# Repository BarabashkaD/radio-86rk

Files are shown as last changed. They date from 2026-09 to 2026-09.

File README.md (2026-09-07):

# Radio 86RK
Re-make of the Soviet Ham Radio computer published in Radio Magazine in 1986

## Hardware Documentation

## Table of Content
* [Introduction](#introduction)
* [Specifications](#specifications)
* [Verification](#verification)
* [KiCad 10](#kicad-10)
  * [Prerequisites](#prerequisites)
  * [Mechanical export, for case design](#mechanical-export-for-case-design)
* [Project Notes](#project-notes)
* [Hardware Documentation](#hardware-documentation)
  * [Schematic and PCB Layout](#schematic-and-pcb-layout)
  * [Connectors](#connectors)
  * [Bill of Materials](#bill-of-materials)
  * [Memory Map](#memory-map)
* [Firmware Documentation](#firmware-documentation)
  * [Monitor](#monitor)
* [Release Notes](#release-notes)
  * [Changes](#changes)
  * [Known Issues](#known-issues)

## Introduction
This project is a remake of [Radio-86RK](https://en.wikipedia.org/wiki/Radio-86RK) - a soviet ham radio computer. The original design was published in Radio Magazine, an amateur radio and DIY electronics oriented publication, starting from [April 1986](Radio-86RK_Publications.md). Hence the "Radio" and "86" in the name ("RK" stands for ham radio computer).

The goal of the original design was to create a computer that can be built relatively easily and cheaply using commonly available components. Therefore it included several short-cuts. For example it didn't use 8228 bus controller. Instead, it uses */WR* and *DBIN* CPU signals instead to distinguish between write and read CPU cycles. Since the system doesn't decode I/O control signals, all the I/O devices are memory mapped. Another optimization is the use of DMA controller for both supplying the data to the CRT controller and for refreshing DRAMs. The system didn't support interrupts. The sound was implemented using *INTE* output of the CPU. The software would use **EI**/**DI** instructions to generate sound. There are no graphics capabilities. The font size was limited to 128 characters (8275 CRT controller limitation), and given that it had to support both Latin and Cyrillic ABCs, it only had capital letters for both ABCs. The CRT controller shares 16 MHz clock oscillator with the CPU (not uncommon in other home computers at that time period).

Despite the limitations, the design was fairly successful, many people have built this computer, and there are some that still building one, this project included. In addtion, several factories manufactured computers based on (but not always compatible with) this design - e.g. [Mikrosha](https://oldcomputer.info/8bit/mikrosha/index.htm), [Apogee BK-01](https://ru.wikipedia.org/wiki/%D0%90%D0%BF%D0%BE%D0%B3%D0%B5%D0%B9_%D0%91%D0%9A-01), and a few more.

### Specifications of the Original Design
  * KR580VM80A (Intel 8080) CPU @ 1.78 MHz (16 MHz divided by 9)
  * 16 KiB to 32 KiB DRAM, 2 KiB ROM (monitor software)
  * KR580VG75 (Intel 8275) CRT controller which works together with KR580VT57 (Intel 8257) DMA controller. 1 KiB ROM is used for font
  * Two KR580VV55A (Intel 8255A) PPIs. One is used for keyboard and cassette I/O, another one for the extension port
  * Normally the computer consisted of 2 or 3 PCBs - the mainboard, the keyboard, and the keypad.

### Modifications to the Original Design
 * 16 DRAM ICs replaced with a single 32 KiB SRAM IC
 * Font ROM size increased to 2 KiB, so that it fits an alternative font. CRT controller GPA0 attribute is used to switch between fonts.
 * Reverse video attribute implemented in CRT controller
 * Added 8251 USART and 8253 timer. The timer is used for dividing the clock for USART and for sound generation.
 * Single board design, including an integrated mechanical keyboard
 * The work is largely based on [Radio-86RК-SRAM](http://radio86rk.pbworks.com/w/page/58467718/Radio-86R%D0%9A-SRAM) project created by Alexey Khudyakov (alexcp).

Radio-86RK

## Specifications
* Processor: Intel 8080A / КР580ВМ80А CPU running at 1.78 MHz
* Memory:
  * RAM: 32 KiB SRAM
  * ROM: 2 KiB UV EPROM with system monitor software
* Video: Intel 8275 / КР580ВГ75 CRT Controller
  * Alphanumeric display
  * 2 KiB UV EPROM with font
  * Composite video output (50 Hz)
* Audio:
  * Intel 8253 / КР580ВИ53 (single channel)
  * CPU INTE output
* Parallel Interface:
  * Intel 8255А / КР580ВВ55А PPI
  * 26-pin expansion header
* Serial Interface:
  * Intel 8251А / КР580ВВ51А USART
  * DE-9 connector
* Built-in 67-keys keyboard
* Cassette recorder interface

## Verification

This repository includes a small, dependency-free harness that proves the
board's copper, connectivity and rule counts have not changed since the
committed baseline. Requires KiCad 10+ and Python 3.8+, no install step:

```
python3 tools/kicad-verify.py all
```

See [`tools/README.md`](tools/README.md) for the full command reference,
exit codes, and how to reuse it on another project.

## KiCad 10

This fork's KiCad files have been modernized to KiCad 10 format. **The board is
unchanged**: the gerber and drill output is identical to skiselev's v1.4, verified
automatically rather than asserted. All footprints and symbols are vendored into the
repository, so the project opens from a fresh clone with no external checkouts.

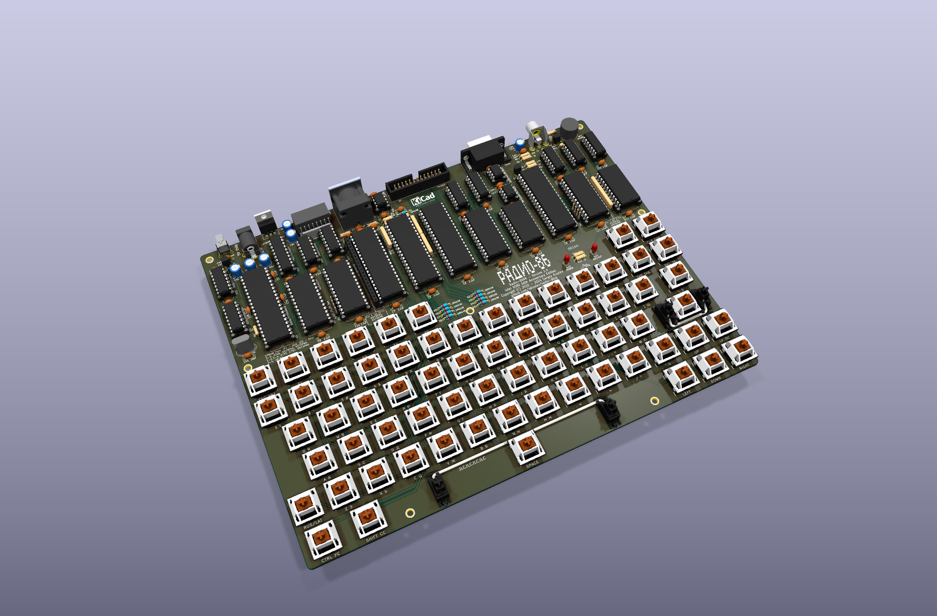
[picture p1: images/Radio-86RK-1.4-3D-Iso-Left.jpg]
Radio-86RK rendered from the KiCad 10 project


The rear panel, with every external connector in one row — composite video, serial,
parallel, cassette, sound and power:

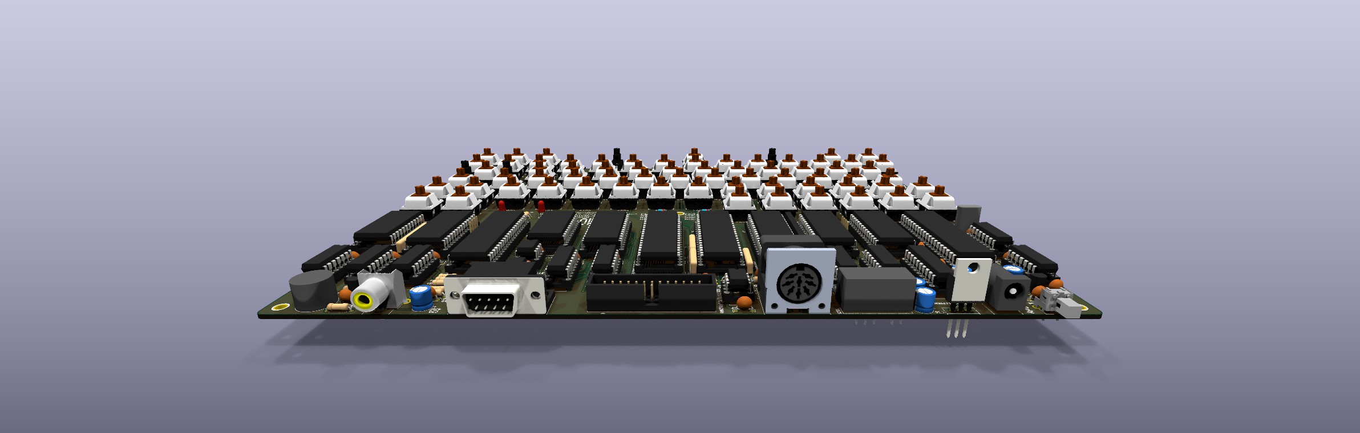
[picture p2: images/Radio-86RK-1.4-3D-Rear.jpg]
Rear connectors


Also rendered: [top](images/Radio-86RK-1.4-3D-Top.jpg) ·
[from the right](images/Radio-86RK-1.4-3D-Iso-Right.jpg) ·
[solder side](images/Radio-86RK-1.4-3D-Bottom.jpg), which carries the memory map, the
monitor command list and the subroutine table in silkscreen.

### Prerequisites

* **KiCad 10.0.4** or newer.
* The **Keyswitch Kicad Library**, v2.4, from KiCad's Plugin and Content Manager —
  package `com.github.perigoso.keyswitch-kicad-library`, upstream
  [github.com/kiswitch/keyswitch-kicad-library](https://github.com/kiswitch/keyswitch-kicad-library),
  CC-BY-SA-4.0. It supplies three model files that 69 of this board's 209 model
  references depend on: the Cherry MX switch body shared by all 67 keys, and two
  stabilizers. Without it the board still opens, routes and exports correctly — only the
  keyboard renders empty in the 3D view.

Check that everything resolves before trusting a render:

```
python3 tools/kicad-verify.py models
```

It reports 183 / 183 footprints covered when the library is installed, and names the
path variable responsible when it is not.

- [Modernization summary](docs/modernization-summary.md) — before/after, and how to re-verify
- [3D model sources](docs/3d-model-sources.md) — every model choice and substitution
- [Retained DRC violations](docs/drc-exclusions.md) — the 22 inherited from v1.4
- [Retained ERC violations](docs/erc-exclusions.md) — the 32 bus-label warnings
- [3D model follow-ups](docs/followup-3d-models.md) — the five approximations now resolved, and optional keycaps

### Mechanical export, for case design

```
python3 tools/export_mech.py            # STEP + placement CSV into .build/mech/
```

Writes four STEP files sharing one datum — the whole assembly, the parts needing panel
cutouts, the switches alone, and the bare board with its mounting holes — plus a CSV
giving every footprint's position, rotation, value and package.

Keycaps are deliberately absent. A cap is a case parameter rather than a board one: its
envelope drives the top-plate openings and the bezel height, and comparing profiles should
cost one filename, not a re-export. `placement.csv`'s `Package` column is the cap size, so
all 68 caps can be placed from the table.

## Project Notes

Check [Project Notes](Project_Notes.md) for the information about building this project

## Hardware Documentation

### Documentation for the Previous Versions

* [Version 1.3](https://github.com/skiselev/radio-86rk/tree/v1.3)
* [Version 1.2](https://github.com/skiselev/radio-86rk/tree/v1.2)
* [Version 1.1](https://github.com/skiselev/radio-86rk/tree/v1.1)

### Schematic and PCB Layout

* [Schematic - Version 1.4](KiCad/Radio-86RK-Schematic-1.4.pdf)
* [PCB Layout - Version 1.4](KiCad/Radio-86RK-Board-1.4.pdf)

### Connectors

#### J1 - Composite Video

Pin | Description     
--- | ---------------
Tip (the inner contact) | Output: Composite Video
Ring / Sleeve         |	Power: GND

#### J2 - Power (5V)
Connect regulated +5V power supply to this connector.

Note: The 8080A CPU, clock generator, and serial port transmitters and receivers use +12V/-5V/-12V voltages. An on-board DC-DC converter (U26) is used to obtain these voltages. Instead of using the DC-DC converter it is possible to provide these voltages directly to the system using J3 connector.

Pin | Description     
--- | ---------------
Tip (the inner contact) | Power: 5V (positive terminal)
Barrel / Sleeve         |	Power: GND (negative terminal)

#### J3 - Power (5V, 12V, -12V)
Connect regulated 5V/12V/-12V power supply to this connector.

Pin | Description     
--- | ---------------
1, 2, 3 | Power: GND
4, 5, 6 |	Power: 5V
7   |	Power: 12V
8   |	Power: -12V

#### J4 - Cassette Connector
Pin | Description     
--- | ---------------
1, 2, 3, 8   | Power: GND
4   |	Output: Sound output to cassette recorder (line level)
5   |	Input: Sound input from cassette recorder (line level)
6, 7 |	Not connected

#### J5 - Serial Port Connector
Pin | Description     
--- | ---------------
1   | Not connected: DCD
2   | Input: RX
3   | Output: TX
4   | Output: DTR
5   | Power: GND
6   | Input: DSR
7   | Output: RTS
8   | Input: CTS
9   | Not connected: RI

#### J6 - Parallel Port Connector
Pin | Description | Pin | Description
--- | ----------- | --- | ----------------
1   | Output: PC0 | 2   | Input: PA0
3   | Output: PC1 | 4   | Input: PA1
5   | Output: PC2 | 6   | Input: PA2
7   | Output: PC3 | 8   | Input: PA3
9   | Output: PC4 | 10  | Input: PA4
11  | Output: PC5 | 12  | Input: PA5
13  | Output: PC6 | 14  | Input: PA6
15  | Output: PC7 | 16  | Input: PA7
17  | Output: PB7 | 18  | Output: PB0
19  | Output: PB6 | 20  | Output: PB1
21  | Output: PB5 | 22  | Output: PB2
23  | Output: PB4 | 24  | Output: PB3
25  | Power: +5V  | 26  | Power: GND

### Bill of Materials

* [Radio-86RK project on Mouser.com](https://www.mouser.com/ProjectManager/ProjectDetail.aspx?AccessID=d3d8f92a02) - View and order all components except of the PCB, and most Intel 8xxx ICs.

* [Unicorn Electronics](https://www.unicornelectronics.com/prod.htm) is a good source for Intel 8xxx or compatible ICs, 7400-series TTL ICs, and 74LS00-series TTL-LS ICs

Component type     | Reference | Description                                 | Quantity | Possible sources and notes
------------------ | --------- | ------------------------------------------- | -------- | --------------------------
PCB                |           | Radio-86RK PCB                              | 1        | Buy from my Tindie store: [Radio-86RK - PCB](https://www.tindie.com/products/weird/radio-86rk-pcb/) or order from a PCB manufacturer of your choice using provided Gerber or KiCad files
Capacitor          | C1 - C32  | 0.1 uF, MLCC, 5 mm Pitch                    | 32       | Mouser [594-K104K15X7RF53H5](https://www.mouser.com/ProductDetail/594-K104K15X7RF53H5)
Capacitor          | C33 - C38 | 47 uF, 25V, Electrolytic or Organic Polymer | 6 	      | Mouser [80-A750EK476M1EAAE40](https://www.mouser.com/ProductDetail/80-A750EK476M1EAAE40)
Capacitor          | C39       | 0.22 uF, MLCC, 5 mm Pitch                   | 1        | Mouser [810-FG24X7R1H224KNT0](https://www.mouser.com/ProductDetail/810-FG24X7R1H224KNT0)
Capacitor          | C40       | 22 nF, MLCC, 5 mm Pitch                     | 1        | Mouser [810-FG28X7R1H223KNT0](https://www.mouser.com/ProductDetail/810-FG28X7R1H223KNT0)
Capacitor          | C41       | 10 nF, MLCC, 5 mm Pitch                     | 1        | Mouser [810-FG28X7R1H103KNT0](https://www.mouser.com/ProductDetail/810-FG28X7R1H103KNT0)
Capacitor          | C42       | 2.2 nF, MLCC, 5 mm Pitch                    | 1        | Mouser [810-FG28X7R1H222KNT0](https://www.mouser.com/ProductDetail/810-FG28X7R1H222KNT0)
Capacitor          | C43       | 1 nF, MLCC, 5 mm Pitch                      | 1        | Mouser [810-FG28C0G1H102JNT6](https://www.mouser.com/ProductDetail/810-FG28C0G1H102JNT6)
Capacitor          | C44       | 10 pF, MLCC, 5 mm Pitch                     | 1        | Mouser [810-FG28C0G1H100DNT00](https://www.mouser.com/ProductDetail/810-FG28C0G1H100DNT0)
Diode              | D1 - D9  | 1N4148                                       | 9        | Mouser [512-1N4148](https://www.mouser.com/ProductDetail/512-1N4148)
LED                | D10       | LED Indicator, 3 mm, Green                  | 1        | Mouser [630-HLMP-1503-C0002](https://www.mouser.com/ProductDetail/630-HLMP-1503-C0002)
LED                | D11       | LED Indicator, 3 mm, Yellow                 | 1        | Mouser [630-HLMP-1401](https://www.mouser.com/ProductDetail/630-HLMP-1401)
Polyfuse           | F1        | 1.1A, 5 mm Pitch                            | 1        | Mouser [576-16R110BU](https://www.mouser.com/ProductDetail/576-16R110BU)
Connector          | JP1, JP2  | 4 pin header, 2.54 mm Pitch                 | 2        | Mouser [649-68000-204HLF](https://www.mouser.com/ProductDetail/649-68000-204HLF)
Connector          | JP1, JP2  | Jumper, 2.54 mm Pitch                       | 4        | Mouser [806-SX1100-B)](https://www.mouser.com/ProductDetail/806-SX1100-B)
Connector          | J1        | RCA Phono connector, Yellow                 | 1        | Mouser [490-RCJ-014](https://www.mouser.com/ProductDetail/490-RCJ-014)
Connector          | J2        | DC Power Jack, 2mm                          | 1        | Mouser [806-KLDX-0202-A](https://www.mouser.com/ProductDetail/806-KLDX-0202-A)
Connector          | J3        | 8 pin friction lock connector               | 1        | Mouser [571-6404568](https://www.mouser.com/ProductDetail/571-6404568)
Connector          | J4        | DIN 8-pos, Right Angle, PCB mount           | 1        | Mouser [490-SDF-80J](https://www.mouser.com/ProductDetail/490-SDF-80J)
Connector          | J5        | Sub-D DE9M, Right Angle, PCB mount          | 1        | Mouser [523-L717SDE09P1ACH3R](https://www.mouser.com/ProductDetail/523-L717SDE09P1ACH3R)
Connector          | J6        | 13x2 pin header, shrouded                   | 1        | Mouser [517-30326-6002](https://www.mouser.com/ProductDetail/517-30326-6002)
Connector          | J7        | 20x1 pin socket                             | 1        | Mouser [517-929850-01-20-RB](https://www.mouser.com/ProductDetail/517-929850-01-20-RB). Note: Optional, for extension board connection
Transistor         | Q1, Q2    | 2N3904                                      | 2        | Mouser [512-2N3904TA](https://www.mouser.com/ProductDetail/512-2N3904TA)
Resistor           | R1        | 33 ohm                                      | 1        | Mouser [660-CF1/4CT52R330J](https://www.mouser.com/ProductDetail/660-CF1-4CT52R330J)
Resistor           | R2        | 75 ohm                                      | 1        | Mouser [660-CF1/4CT52R750J](https://www.mouser.com/ProductDetail/660-CF1-4CT52R750J)
Resistor           | R3        | 150 ohm                                     | 1        | Mouser [660-CF1/4CT52R151J](https://www.mouser.com/ProductDetail/660-CF1-4CT52R151J)
Resistor           | R4        | 330 ohm                                     | 1        | Mouser [660-CF1/4CT52R331J](https://www.mouser.com/ProductDetail/660-CF1-4CT52R331J)
Resistor           | R5        | 1.5 k                                       | 1        | Mouser [660-CF1/4CT52R152J](https://www.mouser.com/ProductDetail/660-CF1-4CT52R152J)
Resistor           | R6 - R13  | 1 k                                         | 8        | Mouser [660-CF1/4CT52R102J](https://www.mouser.com/ProductDetail/660-CF1-4CT52R102J)
Resistor           | R14       | 2.4 k                                       | 1        | Mouser [660-CF1/4CT52R242J](https://www.mouser.com/ProductDetail/660-CF1-4CT52R242J)
Resistor           | R15       | 12 k                                        | 1        | Mouser [660-CF1/4CT52R123J](https://www.mouser.com/ProductDetail/660-CF1-4CT52R123J)
Resistor Array     | RN1       | 10 k, SIP10                                 | 1        | Mouser [652-4610X-1LF-10K](https://www.mouser.com/ProductDetail/652-4610X-1LF-10K)
Resistor Array     | RN2 - RN4 | 4.7 k, SIP6                                 | 3        | Mouser [652-4606X-1LF-4.7K](https://www.mouser.com/ProductDetail/652-4606X-1LF-4.7K)
Speaker            | SP1       | 12 mm speaker                               | 1        | Mouser [665-AT-1224TWTR](https://www.mouser.com/ProductDetail/665-AT-1224TWTR)
Keyboard Switch    | SW1 - SW67 | Cherry MX Blue (Clicky)                    | 67       | Mouser [540-MX1A-E1NW](https://www.mouser.com/ProductDetail/540-MX1A-E1NW)
Switch Leveling Kit | SW11, SW64 | Leveling kit for MX 1x2, 1x2.25, 1x2.75   | 2        | Mouser [540-G99-0742](https://www.mouser.com/ProductDetail/540-G99-0742)
Switch Leveling Kit | SW64     | Leveling kit for MX 1x8                     | 1        | Mouser [540-G99-0226](https://www.mouser.com/ProductDetail/540-G99-0226) Note: Use the wire from this part and one of 540-G99-0742 to build a through hole leveling kit for the spacebar
Tactile Switch     | SW68      | 6 mm Tactile Switch Right Angle             | 1        | Mouser [653-B3F-3152](https://www.mouser.com/ProductDetail/653-B3F-3152)
Switch Keycap      | SW68      | 4 x 4 mmm Tactile Switch Key Cap, Orange    | 1        | Mouser [653-B32-1020](https://www.mouser.com/ProductDetail/653-B32-1020)
Integrated Circuit | U1        | Intel 8080A / КР580ВМ80А, CPU               | 1        | Unicorn Electronics [8080A](https://www.unicornelectronics.com/IC/8000.html), Jameco [52046](https://www.jameco.com/z/8080A-Major-Brands-IC-8080A-8-Bit-MOS-MPU_52046.html)
Integrated Circuit | U2        | Intel 8224 / КР580ГФ24, Clock Generator     | 1        | Unicorn Electronics [8224](https://www.unicornelectronics.com/IC/8000.html)
Integrated Circuit | U3        | Intel 8251А / КР580ВВ51А, USART             | 1        | Unicorn Electronics [8251A](https://www.unicornelectronics.com/IC/8000.html)
Integrated Circuit | U4        | Intel 8253 / КР580ВИ53, PIT                 | 1        | Unicorn Electronics [8253](https://www.unicornelectronics.com/IC/8000.html), Mouser [968-CP82C54Z](https://www.mouser.com/ProductDetail/968-CP82C54Z)
Integrated Circuit | U5, U6    | Intel 8255А / КР580ВВ55А, PPI               | 2        | Unicorn Electronics [8055A](https://www.unicornelectronics.com/IC/8000.html), Mouser [968-CP82C55A-5Z](https://www.mouser.com/ProductDetail/968-CP82C55A-5Z), Jameco [52732](https://www.jameco.com/z/8255A-5-Major-Brands-IC-8255A-5-Programmable-Peripheral-Interface-40-pin-DIP_52732.html)
Integrated Circuit | U7        | Intel 8257 / КР580ВТ57, DMA Controller      | 1        | Unicorn Electronics [8257](https://www.unicornelectronics.com/IC/8000.html)
Integrated Circuit | U8        | Intel 8275 / КР580ВГ75, CRT Controller      | 1        | Unicorn Electronics [8275](https://www.unicornelectronics.com/IC/8000.html), Jameco [52821](https://www.jameco.com/z/8275-Major-Brands-Programmable-CRT-Controller-DIP-40_52821.html)
Integrated Circuit | U9        | AS6C62256, SRAM 32Kx8                       | 1        | Mouser [913-AS6C62256-55PCN](https://www.mouser.com/ProductDetail/913-AS6C62256-55PCN), Unicorn Electronics [62256LP](https://www.unicornelectronics.com/IC/STATIC.html)
Integrated Circuit | U10, U11  | 2716 / КР573РФ5, 2Kx8 EPROM                 | 2        | Mouser [556-AT28C64B15PU](https://www.mouser.com/ProductDetail/556-AT28C64B15PU), Unicorn Electronics [2716](https://www.unicornelectronics.com/IC/EPROM.html). Note: 2716, 2732, 2764, 27C64 EPROMs, or 28C64 EEPROMs can be used
Integrated Circuit | U12       | 74LS373/К555ИР22, 8-bit Latch, 3-state outputs | 1     | Mouser [595-SN74LS373N](https://www.mouser.com/ProductDetail/595-SN74LS373N)
Integrated Circuit | U13       | 74198/К155ИР13, 8-bit Shift Register        | 1        | Unicorn Electronics [74198](https://www.unicornelectronics.com/IC/7400.html)
Integrated Circuit | U14       | 74LS138/К555ИД7, Decoder 3 to 8 active low outputs | 1 | Mouser [595-SN74LS138N](https://www.mouser.com/ProductDetail/595-SN74LS138N), Unicorn Electronics [74LS138](https://www.unicornelectronics.com/IC/74LS.html)
Integrated Circuit | U15       | 7492/К155ИЕ4, Divide by 12 counter          | 1        | Mouser [595-SN74LS92N](https://www.mouser.com/ProductDetail/595-SN74LS92N), Unicorn Electronics [74LS92](https://www.unicornelectronics.com/IC/74LS.html)
Integrated Circuit | U16       | 7486/К155ЛП5, Quad 2-input XOR              | 1        | Mouser [595-SN74LS86AN](https://www.mouser.com/ProductDetail/595-SN74LS86AN), Unicorn Electronics [74LS86](https://www.unicornelectronics.com/IC/74LS.html)
Integrated Circuit | U17       | 7474/К155ТМ2, Dual D Flip-flop, Set & Reset | 1        | Mouser [595-SN74LS74AN](https://www.mouser.com/ProductDetail/595-SN74LS74AN), Unicorn Electronics [74LS74](https://www.unicornelectronics.com/IC/74LS.html)
Integrated Circuit | U18       | 7408/К155ЛИ1, Quad 2-input AND              | 1        | Mouser [595-SN74LS08N](https://www.mouser.com/ProductDetail/595-SN74LS08N), Unicorn Electronics [74LS08](https://www.unicornelectronics.com/IC/74LS.html)
Integrated Circuit | U19       | 7404/К155ЛН1, Hex Inverter                  | 1        | Mouser [595-SN74LS04N](https://www.mouser.com/ProductDetail/595-SN74LS04N), Unicorn Electronics [74LS04](https://www.unicornelectronics.com/IC/74LS.html)
Integrated Circuit | U20       | 7400/К155ЛА3, Quad 2-input NAND             | 1        | Mouser [595-SN74LS00N](https://www.mouser.com/ProductDetail/595-SN74LS00N), Unicorn Electronics [74LS00](https://www.unicornelectronics.com/IC/74LS.html)
Integrated Circuit | U21       | TL071/К140УД6, Operational Amplifier        | 1        | Mouser [595-TL071IP](https://www.mouser.com/ProductDetail/595-TL071IP)
Integrated Circuit | U22       | SN75154N/К170УП2В, Quad RS-232 Receiver     | 1        | Mouser [595-SN75154N](https://www.mouser.com/ProductDetail/595-SN75154N), Unicorn Electronics [75154](https://www.unicornelectronics.com/IC/INTERFACE.html)
Integrated Circuit | U23, U24  | SN75150P/К170АП2, Dual RS-232 Driver        | 2        | Mouser [595-SN75150P](https://www.mouser.com/ProductDetail/595-SN75150P), Unicorn Electronics [75150](https://www.unicornelectronics.com/IC/INTERFACE.html)
Integrated Circuit | U25       | LM7905/КР1179ЕНВ, Negative 5V 1A Linear Regulator | 1  | Mouser [926-LM7905CT-NOPB](https://www.mouser.com/ProductDetail/926-LM7905CT-NOPB), Unicorn Electronics [7905T](https://www.unicornelectronics.com/IC/VOLT.html)
DC-DC Converter    | U26       | IZ0512, +/-12V +/-125mA, 4.5V-9V input      | 1        | Mouser [209-IZ0512S](https://www.mouser.com/ProductDetail/209-IZ0512S)
Integrated Circuit | U27       | DS1233-5, CPU Supervisory Circuit           | 1        | Mouser [700-DS1233-5T&R](https://www.mouser.com/ProductDetail/700-DS1233-5TR)
Crystal            | Y1        | 16 MHz, Series, HC-49U                      | 1        | Mouser [774-ATS160-E](https://www.mouser.com/ProductDetail/774-ATS160-E)
IC Socket          | U1, U5, U6, U7, U8 | 40 pin DIP                         | 5        | Mouser [649-DILB40P223TLF](https://www.mouser.com/ProductDetail/649-DILB40P223TLF), [517-4840-6000-CP](https://www.mouser.com/ProductDetail/517-4840-6000-CP)
IC Socket          | U3, U9, U10, U11    | 28 pin DIP                                  | 4        | Mouser [649-DILB28P223TLF](https://www.mouser.com/ProductDetail/649-DILB28P223TLF), [517-4828-6000-CP](https://www.mouser.com/ProductDetail/517-4828-6000-CP)
IC Socket          | U4, U13   | 24 pin DIP                          | 2        | Mouser [649-DILB24P-223TLF](https://www.mouser.com/ProductDetail/649-DILB24P-223TLF), [517-4824-6000-CP](https://www.mouser.com/ProductDetail/517-4824-6000-CP)
IC Socket          | U12       | 20 pin DIP                                  | 1        | Mouser [649-DILB20P-223TLF](https://www.mouser.com/ProductDetail/649-DILB20P-223TLF), [517-4820-3000-CP](https://www.mouser.com/ProductDetail/517-4820-3000-CP)
IC Socket          | U2, U14, U22 | 16 pin DIP                               | 3        | Mouser [649-DILB16P-223TLF](https://www.mouser.com/ProductDetail/649-DILB16P-223TLF), [517-4816-3000-CP](https://www.mouser.com/ProductDetail/517-4816-3000-CP)
IC Socket          | U15 - U20 | 14 pin DIP                                  | 6        | Mouser [649-DILB14P-223TLF](https://www.mouser.com/ProductDetail/649-DILB14P-223TLF), [517-4814-3000-CP](https://www.mouser.com/ProductDetail/517-4814-3000-CP)
IC Socket          | U21, U23, U24 | 8 pin DIP                               | 3        | Mouser [649-DILB8P223TLF](https://www.mouser.com/ProductDetail/649-DILB8P223TLF), [517-4808-3000-CP](https://www.mouser.com/ProductDetail/517-4808-3000-CP)

### Memory Map
* 0000h - 7FFFh - SRAM
  * 7600h - 7FFFh - Display buffer and monitor variables
* 8000h - 8FFFh - 8255A PPI (Keyboard, Cassette recorder, Sound control)
  * 8000h - Channel A data
  * 8001h - Channel B data
  * 8002h - Channel C data
  * 8003h - Control word
* 9000h - 9FFFh - 8253 Timer (USART Clock, Sound)
  * 9000h - Channel 0 count
  * 9001h - Channel 1 count
  * 9002h - Channel 2 count
  * 9003h - Control word
* 0A000h - 0AFFFh - 8255A PPI (Parallel Interface)
  * 0A000h - Channel A data
  * 0A001h - Channel B data
  * 0A002h - Channel C data
  * 0A003h - Control word
* 0B000h - 0BFFFh - 8251A USART
  * 0B000h - Data register
  * 0B001h - Command register
* 0C000h - 0CFFFh - 8275 CRT Controller
* 0D000h - 0DFFFh - Unused
* 0E000h - 0EFFFh - 8257 DMA Controller (write only)
* 0E000h - 0FFFFh - Monitor EPROM (read only)

## Firmware Documentation

### Monitor

#### Monitor Commands
* Memory Operations
  * **D\<Start_Address\>,\<End_Address\>** - Display memory content in hexadecimal
  * **L\<Start_Address\>,\<End_Address\>** - Display memory content in ASCII
  * **F\<Start_Address\>,\<End_Address\>,\<Value\>** - Fill memory with the specified value
  * **M\<Address\>** - Modify memory content
  * **T\<Start_Address\>,\<End_Address\>,\<Destination_Start_Address\>** - Copy memory block to destination
  * **C\<Start_Address\>,\<End_Address\>,\<Destination_Start_Address\>** - Compare memory block with destination
  * **S\<Start_Address\>,\<End_Address\>,\<Value\>** - Search memory for a value
  * **R\<ROM_Start_Address\>,\<ROM_End_Address\>,\<Destination_Start_Address\>** - Read from the ROM connected to the Parallel interface to memory
* Run Control
  * **G\<Start_Address\>\[,End_Address\]** - Run code, optionally stop at the specified address
  * **X** - Display and modify registers
* Cassette Input/Output
  * **O\<Start_Address\>,\<End_Address\>\[,Speed\]** - Write memory to cassette. Default speed is 1Dh / 1200 bps
  * **I\[Offset\]\[,Speed\]** - Read data from to cassette memory at specified offset

#### Monitor Subroutines:
* 0F803h - Keyboard input
  * Input: None
  * Output: A - character code read from keyboard
* 0F806h - Cassette input
  * Input: A=0FFh - with sync; A=08h - no sync
  * Output: A - data read from cassette
* 0F809h - Print character to screen
  * Input: C - character to print
* 0F80Ch - Cassette output
  * Input: C - data to write
* 0F812h - Query keyboard
  * Output: A=00h - key not pressed; A=0FFh - key pressed
* 0F815h - Print to screen in hex
  * Input: A - data to print
* 0F818h - Print string
  * Input: HL - string address
* 0F81Bh - Get key
  * Output: A=0FFh - key not pressed; A=0FEh - Rus/Lat; otherwise A - key code
* 0F81Eh - Get cursor position
  * Output: H - row, L - column
* 0F821h - Read character from screen at current cursor position
  * Output: A - char read from screen
* 0F824h - Read from cassette
  * Input: HL - offset of memory buffer to store data to
  * Output: HL - start; DE - end; BC - checksum

## Release Notes

### Changes
* Version 1.4
  * Change keyboard layout to QWERTY
  * Add the J7 extension connector
  * Add support for 2732, 2764 and 27C64 EPROMs and 28C64 EEPROM.

* Version 1.3
  * Fix issues from version 1.1 and version 1.2:
    * Use key labels "Ь X" and "СС SHIFT" on top silkscreen
    * Video signal generation circuit: use R2 = 75 Ohm and R5 = 1.5 kOhm
    
* Version 1.2
  * Add F5 key
  * Add copyright year on the top silkscreen

* Version 1.1
  * Fix all known issues of version 1.0
  * Use DS1233-5 mircoprocessor supervisor to generate reset signal
  * Implement reverse video attribute

* Version 1.0
  * Initial version

### Known Issues
* Version 1.3
  * No known issues

* Version 1.2
  * Top silkscreen: "Ь" and "X" key labels are swapped
  * Top silkscreen: More correct translation for "СС" is "SHIFT"
  * Video signal generation: Produced video Vpp and the backporch levels are a bit too high. Use R2 = 75 to 100 Ohm, and R5 = 1.5 kOhm for proper video signal levels (Reported by Martin Lukasek)
* Version 1.1
  * Top silkscreen: "Ь" and "X" key labels are swapped
  * Top silkscreen: More correct translation for "СС" is "SHIFT"
  * Top silkscreen: No copyright year
  * Video signal generation: Produced video Vpp and the backporch levels are a bit too high. Use R2 = 75 to 100 Ohm, and R5 = 1.5 kOhm for proper video signal levels (Reported by Martin Lukasek)

* Version 1.0
  * 8224 (U2) should use DIP-16 footprint
  * Down and Right buttons swapped
  * Reset RC does not provide enough time for the system to properly reset at power-on

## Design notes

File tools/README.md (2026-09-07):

# kicad-verify: a verification harness for KiCad projects

## What it does

This tool proves that a KiCad project's copper, connectivity and rule counts
have not changed since a known-good point. It compares the current board and
schematic against a captured baseline, and tells you exactly which of those
three things moved, if any.

It does not tell you whether your design is *good*. It tells you whether it
is *the same as before*, in the specific ways that are easy to break by
accident: a net silently reassigned, copper that shifted, a footprint that
lost a pad.

## How to run it

There is no install step. Clone the repository and run:

```
macOS / Linux:   python3 tools/kicad-verify.py all
Windows:         py tools\kicad-verify.py all
```

That runs every check (`gerber`, `netlist`, `rules`) and prints one verdict
line per gate, followed by a combined verdict for the run.

## Requirements

- KiCad 10 or newer (specifically `kicad-cli`, KiCad's command-line tool,
  which ships inside every KiCad 10 install).
- Any Python 3.8 or newer. The standard library only — nothing to `pip
  install`, no virtual environment, no configuration file.

The harness looks for `kicad-cli` in the usual per-OS install locations and
on `PATH`. If it cannot find one, or you want to point it at a specific
install, set the `KICAD_CLI` environment variable to the full path of the
`kicad-cli` executable:

```
export KICAD_CLI=/path/to/kicad-cli          # macOS / Linux
set KICAD_CLI=C:\path\to\kicad-cli.exe        # Windows
```

`KICAD_CLI` is authoritative once set: if it points at something that does
not run, the harness fails with an error naming that path rather than
silently falling back to some other `kicad-cli` it finds elsewhere on the
machine. That is deliberate — a tool that quietly ran a different KiCad than
the one you chose would be worse than one that stops and says so.

## The commands

Run as `python3 tools/kicad-verify.py <command>` (macOS / Linux) or
`py tools\kicad-verify.py <command>` (Windows).

| Command | What it does |
|---|---|
| `doctor` | Checks the environment: is `kicad-cli` found, is it new enough, is there a project, and is there a baseline the gates can actually use (`strict/` and `netlist.nets` present). Exits `0` if everything needed is present, `2` if not. Run this first when anything else fails unexpectedly. |
| `baseline` | Captures a new reference snapshot of the board's gerbers, drill files and netlist connectivity into `verify/baseline/`. Fails if a baseline already exists there; pass `--force` to overwrite it. Pass `--geometry` to instead capture (or refresh) the geometry-only baseline alongside it — see [Using `--geometry`](#using---geometry) below. |
| `gerber` | Exports gerbers and drill files from the current board, canonicalises them, and compares them against the committed baseline. Reports whether the copper is unchanged. |
| `netlist`  | Exports the netlist from the current schematic and compares its connectivity (which pin is on which net) against the baseline. Reports whether the wiring is unchanged. |
| `rules` | Runs ERC and DRC and reports the violation counts, by type. This is informational, not pass/fail — see [Why `rules` reports instead of judging](#why-rules-reports-instead-of-judging) below. |
| `models` | Reports which 3D model references resolve on this machine: how many footprints have a model KiCad can find, which do not, and which KiCad path variable is responsible when one cannot be resolved at all. Informational, like `rules`. Needs no `pcbnew` and no `kicad-cli` — it reads the board as text, so it still answers on a machine where KiCad is not set up, which is where the question usually arises. |
| `all` | Runs `gerber`, `netlist` and `rules` in order, and prints a combined verdict. This is the one command most people want. |
| `run` | `run <script> [args]` executes a script under the interpreter that can import `pcbnew` — the four model tools in `tools/` need it and no plain interpreter provides it. A passthrough: the script's stdout, stderr and exit code are its own, and no verdict line is written. Set `KICAD_PY` to override discovery. |
| `selftest` | Runs the harness's own internal checks (currently 24) against fixtures. Tests the tool itself, not your project — it needs no KiCad install and no board. |

Useful flags, valid on every command above: `--json` (emit one JSON document
instead of verdict lines), `--verbose` (show tool output that is normally
filtered as noise), `--project PCB` (point at a specific `.kicad_pcb` if more
than one exists), `--baseline-dir DIR` (use a baseline somewhere other than
`verify/baseline`). Two more flags apply to specific commands: `--force`
(`baseline`: overwrite an existing baseline of the same mode) and `--geometry`
(`baseline` and `gerber`: use the geometry-only baseline instead of the
committed strict one — see below).

## Verdict statuses

Each gate's line on stdout begins with one of three statuses, and `--json`
records the same value in that gate's `"status"` field. The one exception is
`run`, which writes no verdict line at all: it is a passthrough, so its stdout
belongs to the script it launched and its exit code is that script's.

| Status | Meaning |
|---|---|
| `PASS` | The gate ran and found no difference from the baseline. |
| `FAIL` | The gate ran and found a difference from the baseline. |
| `INFO` | The gate ran and is reporting a count, not a verdict. `rules` (see below) and `models`. An `INFO` gate never causes exit code `1`, and `all`'s combined "N of N gates passed" line does not count it either way. |

## Why `rules` reports instead of judging

`rules` runs ERC and DRC and prints the violation counts, by type. It always
returns `INFO`, never `PASS` or `FAIL`, and it never affects `all`'s exit
code.

There is no baseline for rule counts to compare against, on purpose: unlike
copper and connectivity, the number of ERC/DRC violations legitimately
changes as a project is worked on, and a change in that count is not
automatically a regression. It also means this repository's own current
counts can include violations that are already understood and accepted
rather than accidentally introduced: as of this writing, DRC reports 5
`starved_thermal` errors, a known property of this board's thermal relief
pattern, not something `rules` is equipped to distinguish from a genuine new
problem. Reading the counts and the by-type breakdown, and deciding whether a
change in them is expected, is on the person or agent running the tool.

## Using `--geometry`

`gerber`'s default ("strict") comparison includes the X2 net and component
name attributes KiCad embeds in each gerber, so a net rename shows up even
when no copper moved. `--geometry` drops those attributes and compares copper
shape only — for a change that legitimately renames nets without moving
anything.

The geometry baseline is deliberately not committed (only `strict/` and
`netlist.nets` are). To use it, capture it yourself into the same baseline
directory:

```
python3 tools/kicad-verify.py baseline --geometry
python3 tools/kicad-verify.py gerber --geometry
```

Capturing geometry never touches the committed `strict/` baseline, and
capturing strict never touches `geometry/` — each `--force` applies only to
the mode you are capturing. If you want to keep a geometry baseline out of
the repository entirely (recommended, since it is deliberately uncommitted),
point both commands at a directory outside the repo with `--baseline-dir`.

## The three exit codes, and why there are three and not two

| Exit code | Meaning |
|---|---|
| `0` | Every gate passed. Nothing changed. |
| `1` | A gate failed. The board genuinely changed. |
| `2` | A check could not run at all — no `kicad-cli` found, no baseline captured, no board in the repository, an unexpected error. |

This distinction is the single most important thing to understand about this
tool, and it is easy to get wrong if you only skim the output. `1` means
"the board changed." `2` means "I don't know, because the check never ran."
Those are different facts, and collapsing them is a real hazard: a script,
CI job, or agent that treats any non-zero exit as "a regression" will report
a copper change that never happened, just because `kicad-cli` was not on
`PATH` that day. Always branch on the exit code, not just on "zero or
non-zero."

## What the version warning means

If the harness runs under a different major version of KiCad than the one
that captured the current baseline, it prints a `VERSION-DRIFT` warning to
stderr and (in `--json` mode) sets `"version_drift": true` on the affected
gates.

This is **not** a failure, and it never changes the exit code by itself.
KiCad's own exporters occasionally change their output between major
versions in ways that are cosmetic — reordered attributes, a different
comment string — with no actual change to the board. The warning means: go
read the KiCad changelog for the version jump, and confirm that whatever
difference the gate reports (if any) is one of those emitter changes and not
a real one. It exists because those two situations look identical in a diff
but mean very different things.

## Using it on another project

This harness is not specific to this repository. To use it on a different
KiCad project, copy two things into it:

- `tools/kicad-verify.py`
- `tools/kicadverify/` (the whole directory)

Then, from inside that project's repository, run:

```
python3 tools/kicad-verify.py baseline
```

once, to capture the reference snapshot, and commit the resulting
`verify/baseline/` directory. After that, `python3 tools/kicad-verify.py all`
works the same way it does here. No project name, board name, or file path is
hard-coded anywhere in the tool — it discovers the `.kicad_pcb` in the
repository itself.

## What is deliberately not here

These were left out on purpose, not forgotten:

- **CI / GitHub Actions.** A workflow running `selftest` and `all` on every
  push would need a runner with KiCad 10 installed, which pins a specific
  KiCad version as its own piece of work. The harness's three exit codes,
  `--json` output, and lack of any interactive input are all there to make
  that straightforward to add later.
- **Packaging** the harness as a standalone, independently versioned
  component with its own repository.
- **A test framework** beyond `selftest`, should the harness ever grow past
  what its fixture-based checks can cover.

See also [`docs/harness-equivalence.md`](../docs/harness-equivalence.md) for
the evidence that this harness checks the same things the shell scripts it
replaced checked.

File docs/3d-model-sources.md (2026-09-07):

# 3D model sources and substitutions

Per the design spec's equivalence rubric, the 3D layer is appearance-only: it touches no
copper, so visually equivalent public models are preferred over exact ones. Every
substitution is recorded here.

Models attach to footprint *definitions*, not to references, which is why 76 components are
covered by 8 assignments. Paths use `${KICAD10_3DMODEL_DIR}`, `${KICAD10_3RD_PARTY}` or
`${KIPRJMOD}` so the project stays portable. KiCad 10 ships `.step` files, not `.wrl`.

Coverage is measured with `the `models` command`, which counts only models whose file
actually resolves — the board began with 109 footprints carrying KiCad-4-era references
(`dil/`, `discret/`, `pin_array/`) that pointed at nothing.

## Passives — 76 components, 8 footprints

| Footprint | Refs | Count | Model | Note |
|---|---|---:|---|---|
| `Res_762` | R1–R15 | 15 | `Resistor_THT/R_Axial_DIN0207_L6.3mm_D2.5mm_P7.62mm_Horizontal` | exact lead pitch |
| `Cap_Cer_508` | C1–C32, F1 | 39 | `Capacitor_THT/C_Disc_D5.0mm_W2.5mm_P5.00mm` | see F1 note |
| `Cap_Elec_Radial_6.3mm` | C33–C38 | 6 | `Capacitor_THT/CP_Radial_D6.3mm_P2.50mm` | exact |
| `Diode_762` | D1–D9 | 9 | `Diode_THT/D_DO-35_SOD27_P7.62mm_Horizontal` | exact |
| `LED_3mm` | D10, D11 | 2 | `LED_THT/LED_D3.0mm` | exact |
| `Crystal_HC-49U_Vert` | Y1 | 1 | `Crystal/Crystal_HC49-U_Vertical` | exact |
| `Transistor_TO92_EBC_254` | Q1, Q2, U27 | 3 | `Package_TO_SOT_THT/TO-92_Inline` | generic TO-92 for the Soviet KT-series |
| `IC_TO220-3_Vert` | U25 | 1 | `Package_TO_SOT_THT/TO-220-3_Vertical` | exact package |

**F1 renders as a disc capacitor.** F1 is a fuse but is placed on the `Cap_Cer_508`
footprint, and models attach to footprints rather than to references. Splitting the
footprint solely to change F1's appearance would mean a second library part with identical
copper — cost without benefit. Accepted under the tolerance policy.

**U27 is a TO-92 transistor, not a regulator.** The design spec's prose calls U25 and U27
regulators; the board says `Transistor_TO92_EBC_254`. The board is right.

## Socketed DIP ICs — 24 components, 7 footprints

Every DIP on this board sits in a socket, so each DIP footprint carries **two** models: the
socket at board level and the chip raised to the socket's seating height. U25 (TO-220),
U26 (SIP DC-DC) and U27 (TO-92) are not DIP parts and take a single model each.

| Footprint | Refs | Socket (z=0) | Chip (z=offset) | Offset |
|---|---|---|---|---:|
| `IC_DIP8_300` | U21, U23, U24 | `DIP-8_W7.62mm_Socket` | `DIP-8_W7.62mm` | 5.1 |
| `IC_DIP14_300` | U15–U20 | `DIP-14_W7.62mm_Socket` | `DIP-14_W7.62mm` | 5.48 |
| `IC_DIP16_300` | U2, U14, U22 | `DIP-16_W7.62mm_Socket` | `DIP-16_W7.62mm` | 5.48 |
| `IC_DIP20_300` | U12 | `DIP-20_W7.62mm_Socket` | `DIP-20_W7.62mm` | 5.48 |
| `IC_DIP24_600` | U4, U13 | `DIP-24_W15.24mm_Socket` | `DIP-24_W15.24mm` | 5.48 |
| `IC_DIP28_600` | U3, U9, U10, U11 | `DIP-28_W15.24mm_Socket` | `DIP-28_W15.24mm` | 5.48 |
| `IC_DIP40_600` | U1, U5–U8 | `DIP-40_W15.24mm_Socket` | `DIP-40_W15.24mm` | 5.48 |

Row spacing follows the board: `*_300` footprints are 300 mil (7.62 mm), `*_600` are
600 mil (15.24 mm).

**Where the heights come from.** The prototype uses Amphenol FCI DILB `-223TLF`
stamped-and-formed sockets. Amphenol's spec sheet publishes Dim A/B/C/D, pitch, row spacing
and tail length but no overall height. Distributor package data reports 5.48 mm for the 14,
16, 28 and 40 position parts and for the 0.3″ sibling `DILB24P-224TLF`, across both row
spacings and from 14 to 40 positions. Height is a property of the insulator's extruded
cross-section and does not vary with body length, so 5.48 mm is taken for the 20- and
24-pin as well. The 8-pin at 5.1 mm is the only outlier.

This is a 3D-appearance parameter, not a geometry one: a 0.38 mm error would be invisible
in the viewer and cannot reach the board.

**Western parts, not Soviet.** The prototype is populated with Intel `P8255A-5`, NEC
`8257C-5`, TI `SN74198N` and `74LS74` rather than the Soviet equivalents in the dual
silkscreen markings, so package choices follow the Western parts.

## Connectors, arrays and misc — 15 components, 12 footprints

| Footprint | Refs | Model | Fidelity |
|---|---|---|---|
| `Conn_SIL6` | RN2–RN4 | `Resistor_THT/R_Array_SIP6` | exact pin count and pitch |
| `Conn_SIL10` | RN1 | `Resistor_THT/R_Array_SIP10` | exact pin count and pitch |
| `Conn_Pin_Header_4x1_2.54mm` | JP1, JP2 | `PinHeader_1x04_P2.54mm_Vertical` | exact |
| `Conn_Pin_Header_20x1_2.54mm` | J7 | `PinSocket_1x20_P2.54mm_Vertical` | female — see below |
| `Conn_Pin_Header_13x2_2.54mm_Shrouded` | J6 | `IDC-Header_2x13_P2.54mm_Vertical` | exact |
| `Conn_Friction_Lock_8P_2.54mm` | J3 | `Radio86RK.3dshapes/640456-8` | **the real part** — see below |
| `Conn_Power_Jack_Circular_Pads` | J2 | `Radio86RK.3dshapes/KLDX-0202-A` | **the real part** |
| `Conn_Dsub_DE9M` | J5 | `DSUB-9_Pins_Horizontal_P2.77x2.84mm_EdgePinOffset7.70mm_Housed_MountingHolesOffset9.12mm` | housed, with mounting hardware |
| `Speaker_12mm` | SP1 | `Radio86RK.3dshapes/AT-1224-TWT-R` | **the real part** |
| `DC-DC_SIP8` | U26 | `Radio86RK.3dshapes/IZ0512S` | scaled sibling — see below |

`RN1`–`RN4` are SIP resistor networks, so `R_Array_SIP6`/`SIP10` are used rather than pin
headers — same pin count and pitch, correct body.

**J7 is a socket, not a header, despite its footprint name.** The name
`Conn_Pin_Header_20x1_2.54mm` is inherited from the board and cannot change without
changing a `lib_id`, but skiselev's BOM calls for a 3M **929850-01-20-RB** — a female
receptacle strip (Mouser 517-929850-01-20-RB) for the optional extension board. It rendered
as 20 male pins until this was caught in a render. KiCad's `PinSocket_1x20_P2.54mm_Vertical`
has pads identical to the header's, so only the model changed and the transform is
unaffected. J6 and JP1/JP2 were checked against the BOM at the same time and are genuinely
male headers.

### The seven KiCad does not ship

KiCad has no RCA, cinch or phono model, no 8-pin DIN, and nothing for the XP Power IZ
series — searched every installed `.3dshapes` directory including the PCM third-party
libraries. (The one "DIN" hit is `Jack_3.5mm_Ledino_KB3SPRS`, whose *part name* contains
the string.) Four more parts had a stock model that was the right *category* and the wrong
manufacturer.

All seven came from the abandoned `migrate2kicad10` branch, which attacked the same problem
from the opposite end: it replaced each footprint with a manufacturer-sourced one that
carried its own model. Those footprint swaps moved copper and are unusable here — but a
model does not care which footprint introduced it, and the STEP files are the real parts
from skiselev's BOM. They are vendored into `KiCad/Radio86RK.3dshapes/` and referenced via
`${KIPRJMOD}`, so a fresh clone renders them with nothing installed.

| Ref | Part | STEP origin |
|---|---|---|
| J1 | Same Sky / CUI **RCJ-014** RCA phono | SnapEDA (`CUI_DEVICES_RCJ-014.step`) |
| J2 | Kycon **KLDX-0202-A** 2 mm DC jack | SamacSys / Ultra Librarian (`KLDX-0202-A.STEP`) |
| J3 | TE / AMP **640456-8** MTA-100 header | Tyco Electronics (`C-640456-8`, 2013) |
| J4 | Same Sky / CUI **SDF-80J** DIN-8 | manufacturer (`same sky SDF-80J.STEP`) |
| SP1 | PUI **AT-1224-TWT-R** 12 mm transducer | SamacSys, via FreeCAD/OCC |
| SW68 | Omron **B3F-3152** tactile | manufacturer (`B3F_3152.step`) |
| U26 | XP Power **IZ0512S** DC-DC | sibling IA0512S, scaled — below |

**The models are checked against our pads before being reused.** Two libraries drawing the
same part is a premise, not a fact, so `tools/align_models_legacy.py` brute-forces the four
90° rotations, lands our pad 1 on theirs, and reports the worst distance from any of our
pads to the nearest same-named pad of theirs:

| Footprint | fit rotation | worst pad residual |
|---|---:|---:|
| `DC-DC_SIP8` | 0° | 0.0000 mm |
| `Conn_DIN_8pin` | 180° | 0.0000 mm |
| `Conn_Friction_Lock_8P_2.54mm` | 180° | 0.0000 mm |
| `Switch_Tactile_6mm_Right` | 180° | 0.0009 mm |
| `Speaker_12mm` | 90° | 0.0024 mm |
| `Conn_Power_Jack_Circular_Pads` | 0° | 0.1006 mm |
| `Conn_RCA_Right` | 0° | 0.5800 mm |

J1's 0.58 mm is a known error in the *board's* own hand-drawn footprint: measured against
the RCJ-01 datasheet, the manufacturer's signal-to-odd-ground spacing is right and the
board's is 0.58 mm out. It is copper, so it stays as it is; at the 3D layer it is invisible.

#### U26 is the one model that is not the real part

No STEP exists for the IZ0512S anywhere. The old branch substituted the manufacturer's
model for the sibling **IA0512S** — same potted-SIP construction — and scaled it to the IZ's
body. That is a sound approach, and its two ratios were right, but they were applied to the
wrong axes.

The branch's note orders both parts *L × H × W*: IA `19.3 × 10.1 × 6.0`, IZ
`21.85 × 11.10 × 9.20`. The IZ figures are correct — page 1 of
`Documentation/XP Power - DC-DC Converter - IZ Series.pdf` gives 0.86″ (21.85) long,
0.44″ (11.10) high and 0.36″ (9.20) wide on the bottom view. But the STEP itself is authored
Z-up, so *its* axes run L × W × H; measuring the file gives X 19.30, Y 6.09, Z −5.00…10.16.
Stored as `(1.1321, 1.0990, 1.5333)` the height ratio lands on width and the width ratio on
height, rendering U26 about **15.6 mm tall and 6.7 mm thick** instead of 11.10 × 9.20 — a
brick with the right footprint and visibly wrong proportions, filling only part of the v1.4
silkscreen outline.

Corrected to `(1.1321, 1.5107, 1.0925)` in `align_models_legacy.py`'s `SCALE_FIX`, so
re-running the tool reproduces the fix rather than the bug. The body now fills its silk
outline. The board is designed to accept alternatives anyway (README: Traco TMR 3E, Recom
RS3, Cincon EC3SA), so a correctly-proportioned SIP brick of the right family is a fair
representation even though the mould is a sibling's.

#### Licensing

All seven are vendor-published mechanical models, redistributed from the manufacturer or
from SnapEDA / Ultra Librarian exports of manufacturer data. They are geometry for
documentation and rendering, carry no copper, and are not part of the fabrication output —
the gerbers are byte-identical with or without them.

## Keyboard — 68 switches, 6 footprints

| Footprint | Refs | Model(s) | Note |
|---|---|---|---|
| `CHERRY_PCB_100H` | 62 keys | `SW_Cherry_MX_PCB` | perigoso, via PCM |
| `CHERRY_PCB_125H` | SW65, SW66 | `SW_Cherry_MX_PCB` | |
| `CHERRY_PCB_150H` | SW61 | `SW_Cherry_MX_PCB` | |
| `CHERRY_PCB_225H` | SW11 | `SW_Cherry_MX_PCB` + `Stabilizer_Cherry_MX_2.00u` | composite |
| `CHERRY_PCB_625H` | SW64 | `SW_Cherry_MX_PCB` + `Stabilizer_Cherry_MX_6.25u` @ 180° | composite, mirrored |
| `Switch_Tactile_6mm_Right` | SW68 | `Radio86RK.3dshapes/B3F-3152` | reset switch, the real Omron part |

**The footprints are the board's own, not perigoso's.** Only the models come from perigoso.
The design spec proposed adopting perigoso's footprints on the grounds that doing so
"brings a 3D model", but models attach to any footprint by name, and both libraries put the
switch's centre guide boss at (0, 0) — verified — so the model lands correctly on the
original geometry with no offset.

Keeping the board's footprints avoided a 2.286 → 2.5 mm pad growth on 67 switches, the
compensating schematic pin swap, two clearance violations at 0.150 mm needing prototype
measurement, and the loss of SW11/SW64's stabilizer holes. Cost: perigoso's tidier
silkscreen and a real `F.CrtYd` courtyard. Cherry specifies hole sizes (⌀1.5 mm terminals,
⌀4.0 mm boss, ⌀1.7 mm locating pins), not land diameter, so the board's 2.286 mm pads are
as legitimate as perigoso's 2.5 mm.

### Why SW64's stabilizer is rotated 180°

The board mounts the spacebar stabilizer opposite to the 2.25u one, in the footprint's own
frame:

| | ⌀3.9878 (housing) | ⌀3.048 (wire) |
|---|---|---|
| Board SW11 (2.25u) | y = +8.255 | y = −6.985 |
| perigoso `Stabilizer_2.00u` | y = +8.225 | y = −6.985 |
| Board SW64 (6.25u) | y = **−8.255** | y = **+6.985** |
| perigoso `Stabilizer_6.25u` | y = **+8.225** | y = **−6.985** |

A 180° rotation about Z maps (x, y) → (−x, −y). Both patterns are symmetric about x = 0, so
it acts as a pure front-to-back flip and aligns the model with the board's holes. Verified
in a close render of the spacebar row: the housings sit on the board with the wire
spanning between them. At 0° the whole assembly hangs off the board edge, 16.5 mm out.

Per skiselev's README BOM, SW11 and SW64 take Cherry **G99-0742** leveling kits
(Mouser `540-G99-0742`), and SW64 additionally uses the **wire from a G99-0226** (MX 1x8,
`540-G99-0226`) fitted into G99-0742 housings. That hybrid is why SW64's 100.076 mm spacing
matches no stock 6.25u part, and why perigoso's is 38 µm out and mirrored. The stabilizer
models sit 30 µm (SW11) and 38 µm (SW64) from the board's actual hole centres — invisible in
the viewer, and exactly what the 3D tolerance policy exists to permit.

## Coverage

**183 / 183.** The 7 mounting holes and the silkscreen logo are exempt. Nothing is missing:
J4, the last gap, was closed with the manufacturer's own SDF-80J model.

## Validating the render

Automated checks catch missing models; they cannot catch a model that is present but wrong.
Do both.

### Scripted

```bash
python3 tools/kicad-verify.py models                 # counts only resolving models
python3 tools/kicad-verify.py models  # names what has none
```

Coverage counts a footprint as covered only if the model file exists on disk. The board
began with 109 footprints carrying KiCad-4-era references that pointed at nothing, so
"has a model entry" would have scored those as covered.

### Visual, in KiCad

PCB Editor → **View → 3D Viewer** (`Alt+3`). Left-drag rotates, scroll zooms.
**Preferences → Display Options → Raytracing** for a realistic render.
Hiding the board itself makes floating or sunk parts obvious.

### Visual, scripted

Top-down views hide Z errors. A low camera angle is what exposes them:

```bash
# the shot that validates seating heights
kicad-cli pcb render --output check.png --width 1600 --height 700 --quality high \
  --rotate '-72,0,0' --zoom 2.2 --pivot '-2.0,3.0,0' --perspective board.kicad_pcb
```

Reproduce the views this was checked against — renders are build output and are not
committed:
`tools/render.py --view iso-left dip` for socket seating, and `--view back profile` for
switch heights, where the edge-on elevation shows them against each other.

### What to check, and why each could be wrong

| Check | Expected | Failure mode |
|---|---|---|
| DIP seating | chip sitting *in* a socket, socket rails visible beneath | wrong Z offset — 5.1 mm for 8-pin, 5.48 mm otherwise |
| SW64 spacebar | two stabilizer housings straddling the switch, wire between, all **on** the board | wrong rotation — at 0° the assembly hangs 16.5 mm off the edge |
| SW11 (2.25u) | same, no rotation | |
| Edge connectors J2, J5, J6 | bodies pointing **outward** past the board edge | model orientation |
| Y1 crystal | standing upright | vertical vs horizontal model |
| Switch row | uniform height, all flat on the board | |
| J1 | a yellow RCA phono jack, opening past the board edge | wrong rotation would face it inward |
| J4 | a round DIN socket overhanging the edge, body inside its silk outline | composed transform wrong |
| J5 | black housing filling the silk outline, bosses on the two plated mounting holes | wrong housed variant |
| U26 | a squat brick filling its silk outline, not a tall thin one | swapped scale axes |

All of these were checked on the current board and are correct.

## Model alignment — why offsets and rotations are needed

A 3D model is authored in the coordinate frame of the KiCad footprint it ships with. Our
footprints came from a 1986 board through a different library and use different
conventions, so a model dropped in at offset (0,0,0) lands wrong. Three distinct mismatches
were found, all of them by looking at the render:

| Mismatch | Effect | Example |
|---|---|---|
| KiCad puts **pad 1 at the origin**; ours are **centred** | model sits half a pitch off — one lead in a hole, one in mid-air | `Cap_Cer_508` pads at ±2.54; KiCad's at 0 and +5.0 |
| KiCad's DIPs run their long axis along **Y**; ours along **X** | every IC appears rotated 90° | `IC_DIP40_600` is 48.26 × 15.24; KiCad's is 15.24 × 48.26 |
| Some of ours number pads in the **opposite direction** | body reversed — a diode's cathode band at the wrong end | `Diode_762` pad 1 at +3.81; KiCad's at 0 |

None of this touches copper. It is purely how the model is placed for rendering, which is
why both gerber gates passed throughout while the render was visibly wrong.

**KiCad's 3D model offset has Y inverted relative to PCB coordinates** (the 3D view has Y
up, the board has Y down); the Z rotation is not inverted. That was determined empirically
with a calibration board rendering eight candidate conventions
side by side against KiCad's own DIP-40 as a known-good reference, and only one puts the
chip body between its pad rows. It is also why the passives looked right while every IC was
visibly wrong: the passives all have `off_y` = 0, so the inversion changes nothing for them.

`tools/align_models.py` derives the transform from geometry rather than guessing: it takes
the pad-1 → pad-N vector in each footprint, rotates by the angle between them, and
translates so the model's pad 1 lands on ours. The results are written into `models.tsv` as
explicit `off_x`, `off_y`, `off_z`, `rot_z` columns, so the data records what is applied and
the tool records why.

Of 27 footprints with stock KiCad models, **only the switches needed no correction** — and
those were verified separately, since both libraries put the switch's centre boss at (0,0).

### Manufacturer models need two more degrees of freedom

KiCad's own models are all authored Z-up in the footprint frame, so `off_x, off_y, off_z,
rot_z` is enough for them. Vendor models are not: they arrive in whatever frame the vendor's
CAD used — several of these are exported lying on their side and need `rot_x = -90` — and
the U26 substitution needs a scale. `models.tsv` therefore takes five optional trailing
columns, `rot_x rot_y sx sy sz`, defaulting to 0 and 1.

The transforms for those seven are *composed*, not measured: each model already had a
placement inside the old branch's own footprint, and our footprint differs from theirs by a
Z rotation θ and a translation. KiCad renders a model as

```
translate(offset) . Rz(-rot_z) . Ry(-rot_y) . Rx(-rot_x) . scale
```

so pre-multiplying Rz(θ) gives `translate(Rz(θ)·offset + δ) . Rz(-(rot_z + θ)) . Ry . Rx .
scale` — the stored Z rotations simply add, `rot_x`/`rot_y`/`scale` pass through, and the
old offset is rotated by θ before δ is added. `tools/align_models_legacy.py` does this and
prints the rows. J4 is the case that proves the algebra: θ = 180° over a non-zero offset and
an X rotation, and the model lands inside its silkscreen outline to the pixel.

**Automated coverage cannot catch this.** the `models` command proves a model file resolves;
it says nothing about whether the model is placed correctly. Only the render does. See the
validation section above.

### Connector alignment, verified

Checked numerically (does the transform map every pad?) and visually:

| Ref | Footprint | rot | worst pad error | Visual |
|---|---|---:|---:|---|
| J5 | `Conn_Dsub_DE9M` | 180° | 0.107 mm | housing fills the silk outline, shell past the board edge, bosses on the mounting holes |
| J6 | `Conn_Pin_Header_13x2_2.54mm_Shrouded` | 270° | 0.000 mm | shroud opening faces up |
| J7 | `Conn_Pin_Header_20x1_2.54mm` | 270° | 0.000 mm | a socket body with a row of receptacle holes, not pins |
| JP1, JP2 | `Conn_Pin_Header_4x1_2.54mm` | 270° | 0.000 mm | pins on pads, body within the silk outline |
| RN1 | `Conn_SIL10` | 0° | 0.000 mm | |
| RN2–RN4 | `Conn_SIL6` | 0° | 0.000 mm | |
| J3 | `Conn_Friction_Lock_8P_2.54mm` | 180° | 0.000 mm | posts on pads (rotation changed with the 640456-8 model) |

J5's 0.107 mm is KiCad's generic 2.77/2.84 mm DSUB pitch against the board's exact
2.7432/2.8448 (0.108"/0.112"). Neither matters at the 3D layer.

**J5 uses a housed variant, and our footprint does have somewhere to put the hardware.** Its
two 3.05 mm pads named `0` at ±12.494 are the connector's plated mounting holes, sitting on
the centreline between the pin rows — there are no *non-plated* holes, which is a different
thing. Of KiCad's five housed right-angle DE9 models, three put their mounting holes on that
centreline; the `EdgePinOffset4.94mm` and `EdgePinOffset14.56mm_...Offset8.20mm` variants
put them at row-2 height instead, a real mechanical mismatch rather than a naming one. The
three survivors differ only in how far the shell stands off the pins, and the board's near
pin row sits 8.178 mm from the edge, so `EdgePinOffset7.70mm` is the fit and the shell
overhangs by 0.478 mm.

Reference renders: `validate-ic-alignment.png`, `validate-connectors.png`,
`validate-jumpers.png`.

### Polarity, verified against the netlist

Placement being right does not mean *orientation* is right — a diode can sit perfectly on
its pads with the band at the wrong end. Checked through the whole chain rather than by
eye alone.

**Diodes (D1–D9, `Diode_762`).** `Device:D` numbers pin 1 = K (cathode). Our footprint
makes pad 1 the **square** pad at (+3.81, 0) and puts a filled silkscreen band at
x = 0.762…1.27, on the pad-1 side — so the board's own marking agrees that pad 1 is the
cathode. KiCad's `D_DO-35_SOD27_P7.62mm_Horizontal` also puts the cathode at pad 1, and the
transform maps KiCad's pad 1 onto ours, so the model's band lands on the cathode.
Confirmed by rendering the diode rows: square pad and red band on the same end.

**Electrolytics (C33–C38, `Cap_Elec_Radial_6.3mm`).** Symbol `Device:C_Polarized_US`,
pin 1 = +. Our footprint makes pad 1 the square pad and carries a `+` silkscreen at
(−3.175, 2.54), the pad-1 side. Netlist check across all six:

| Cap | pin 1 (+) | pin 2 (−) | |
|---|---|---|---|
| C33, C34 | VCC | GND | ✓ |
| C35 | +12V | GND | ✓ |
| C36 | GND | −12V | ✓ |
| C37 | GND | −5V | ✓ |
| C38 | video in | local net | ✓ coupling cap, not a rail |

C36 and C37 look reversed relative to the others and are **correct**: on a negative rail the
`+` terminal belongs on GND, the more positive node. Every one has pin 1 on the more
positive net.

Rendered top-down, each can shows its pale stripe — the negative
marking — on the side opposite the `+` silkscreen.

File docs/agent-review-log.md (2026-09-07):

# Agent review log

Escapes from agent reviews, one row per escape. Append only.

An **escape** is a defect a review passed over that something later caught — the
controller's own verification, a subsequent task's implementer, a later review, or a gate
failure. The policy that governs this log, including the tripwire that revokes cheap
reviews, is `.claude/skills/agent-review-policy/SKILL.md`.

## Why this file is tracked

The implementation ledgers live under `.superpowers/`, which `.gitignore` excludes as
scratch. A metric that dies with each branch cannot answer the question this log exists to
answer — over time, are cheap reviews good enough? So it lives in `docs/` and survives.

## How to read it

This counts **detected** escapes. An escape nobody ever catches is never recorded here, so
the count is a lower bound and not a miss rate. The sample is small: single-digit reviews
per workstream. Treat the log as a tripwire, not a statistic, and never conclude that cheap
reviews are safe because the log is short — a short log is equally consistent with nobody
having looked.

## Reviews performed

| Date | Workstream | Scope | Model class | Findings raised | Escapes detected |
|---|---|---|---|---|---|
| 2026-09-06 | A · harness | Tasks 1–11, task-by-task | expensive | incl. 1 Critical (exit-code hole), 6 Important | — |
| 2026-09-07 | A · harness | fix wave `2918cdf..e2dcbb6`, 10 items | **cheap** | 0 new; all 10 verdicted addressed | **0 so far** |
| 2026-09-07 | C · agent-flows | `CLAUDE.md`, 5 skills, this log | **cheap** | 1 Minor: an ERC breakdown stated without its measurement marker | **1 Minor** (see below) |
| 2026-09-07 | B · kicad10-3d | design spec, pre-implementation | expensive | 3 Critical, 8 Important, 7 Minor | n/a — no code yet |

## Escapes

| Date | Workstream | Task | Reviewer model | Severity | What was missed | Caught by |
|---|---|---|---|---|---|---|
| 2026-09-07 | C · agent-flows | `changing-the-schematic` ERC figure | cheap | Minor | "18 warnings" for the modernization line — the real figure is 32/0, and 18/0 belongs to `migrate2kicad10`, a branch whose merge-base with the archive is `9476ec3` | B design spike, 2026-09-07 |

## Notes on open rows

**2026-09-07, A, fix wave.** Zero escapes detected, but nothing has yet been built on top
of that review, so it has not really been tested. Record any escape found later against
this row rather than starting a new one.

One item in that review — `I6`, the flatpak candidate shape — was explicitly
**unverifiable on the review host**: no flatpak Linux environment exists on macOS. The
reviewer judged it on the code's merits, as instructed. It should be retested the first
time the harness runs on Linux, and if it fails there, that is an escape belonging to this
row.

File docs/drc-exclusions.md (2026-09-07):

# Retained DRC violations

DRC cannot reach zero on this board, and should not. All 22 remaining violations are
properties of skiselev's v1.4 design, preserved deliberately under the project's
board-is-frozen constraint. None is a migration regression: the gerber and drill output is
byte-identical to v1.4, verified by `python3 tools/kicad-verify.py gerber`.

They are warnings, not errors. `unconnected_items` and `schematic_parity` are both zero.

## 17 × `silk_edge_clearance`

Silkscreen graphics that approach or cross the board outline. KiCad 4 did not check this;
KiCad 10 does. **Every one is on an edge-mounted I/O part**, where a silkscreen outline
crossing the board edge is what you would expect — the connector body overhangs the edge by
design.

| Ref | Part | Count |
|---|---|---:|
| J1 | RCA composite video jack | 2 |
| J2 | Barrel power jack | 2 |
| J4 | 8-pin DIN cassette connector | 3 |
| J5 | DE9 serial connector | 5 |
| SW68 | Tactile reset switch | 2 |
| U25 | TO-220 regulator | 3 |

All sit at y ≈ 0.4–25 mm, along the board's rear I/O edge.

Fixing them means moving silkscreen, which changes the fab output for purely cosmetic
benefit and breaks the byte-identical guarantee.

**Reason to record:** `preserved from v1.4 original, not a regression`

## 5 × `starved_thermal`

Thermal reliefs on the `GND` zone with insufficient spoke connection — KiCad reports
"1 spokes connected to isolated island" on layer B.Cu.

| Pad | Position (mm) |
|---|---|
| C29 pad 1 | (43.18, 54.61) |
| R14 pad 2 | (88.90, 29.21) |
| U7 pad 20 | (109.22, 36.83) |
| U16 pad 7 | (254.00, 26.67) |
| U26 pad 7 | (83.82, 10.16) |

Present in the original routing. Fixing them means altering zone or pad geometry.

**Reason to record:** `preserved from v1.4 original, not a regression`

## Marking them as exclusions in KiCad

The list above is the durable record. Marking each violation as an *excluded* item in
KiCad additionally cleans the DRC panel, and is a GUI action:

In **Pcbnew → Inspect → Design Rules Checker**, run DRC, then right-click each violation →
**Exclude with comment**, pasting the reason above. Save the board and the project.

**This cannot reliably be scripted.** Exclusions live in `Radio-86RK.kicad_pro` under
`board.design_settings.drc_exclusions` as `[serialised_marker, comment]` pairs, where the
serialised marker is `type|posX_nm|posY_nm|uuid|uuid`. Generating those externally was tried
and did not take: `kicad-cli pcb drc` re-runs the check from scratch and builds fresh
markers, so a hand-written entry does not match. Let KiCad write them.

## Not in this list

The keyboard adds nothing. Task 7 attached 3D models to the switch footprints without
replacing them, so no switch geometry changed and no new violation appeared.

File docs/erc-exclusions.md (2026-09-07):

# Retained ERC violations

32 violations remain, all warnings, zero errors. They are recorded here as deliberate
decisions rather than fixed.

## 32 × `same_local_global_label`

Address, data and control-bus signals that carry both a **local** and a **global** label of
the same name on the same sheet: `A0`–`A14`, `D0`–`D7`, the strobes `~{RD}` `~{WR}`
`~{IOR}` `~{MEMW}`, plus `OSC`, `RESET`, `TTL_CLK` on the root sheet, and `SPKR_ENA`,
`PIT2_ENA` on the Keyboard sheet.

KiCad flags the mixed scope as ambiguous to a reader. It is not a defect: each signal
resolves to exactly one net. `A0`, for example, is a single net carrying 10 nodes — the
CPU, both EPROMs, the RAM, the PPI, the DMA controller and the expansion header.

### Why they are not fixed

**The cost is 91 edits, not 32.** ERC reports a violation per *signal name*, not per label.
A signal keeps its warning while **any** local label of that name coexists with the global
one, and each signal carries 2–4 local labels:

| Signal group | Local labels each |
|---|---:|
| `A0`, `A1`, `A2`, `A3`, `A4`, `A5`, `TTL_CLK`, `~{IOR}`, `~{MEMW}` | 2 |
| `A6`–`A11` | 3 |
| `A12`–`A14`, `D0`–`D7`, `RESET`, `~{WR}` | 4 |
| `~{RD}`, `PIT2_ENA`, `SPKR_ENA` | 1 |

**Total: 91 local labels** would have to be deleted or converted to clear all 32 warnings.

This was tested, not assumed. Six local labels were deleted from the root sheet
(`A0`–`A5`); the netlist gate confirmed connectivity was untouched, and the ERC count did
not move — 32 before, 32 after. The change was reverted.

Ninety-one manual edits to a working, frozen schematic, for warnings that carry no errors
and change no copper, is a poor trade. The board's whole premise is that it is preserved
exactly.

### Why not convert them to global labels instead

Converting `label` → `global_label` is mechanically simpler and cannot split a net. It is
rejected anyway: the design spec records that converting local labels to global is what
masked the U3/U22 RS-232 defect on the `migrate2kicad10` branch, by giving those pins a
driver and silencing the connectivity check. Doing it to 91 labels is that same manoeuvre
at scale, and it would change how the schematic reads for no functional gain.

**Reason recorded:** `bus signals carry both label scopes by original design; one net each,
verified in the netlist; fixing costs 91 edits for 0 errors`

## GitHub issue #2 — U3 / U22 RS-232 wiring

Not currently reported. The 8251A (U3) and SN75154 (U22) have receiver input and output
pins wired backwards — a defect in the original v1.4 design, filed as
[issue #2](https://github.com/BarabashkaD/radio-86rk/issues/2).

If resolving further symbol or label links ever makes `pin_not_driven` /
`pin_not_connected` / `unconnected_wire_endpoint` violations appear on U3 or U22, that is
this defect becoming visible — the correct outcome, not a regression. It is **not fixed
here**: correcting it requires moving wire endpoints, a topology change, and this project's
top constraint is that the board is preserved exactly. It must **not** be silenced by
relabelling.

## Marking them as exclusions in KiCad

The list above is the durable record. Marking each violation excluded additionally cleans
the ERC panel, and is a GUI action: **Inspect → Electrical Rules Checker**, run, then
right-click each → **Exclude with comment**.

As with the DRC exclusions, this could not be scripted — see `docs/drc-exclusions.md` for
why.

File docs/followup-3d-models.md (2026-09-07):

# Follow-up: 3D models

The board is finished and verified — copper identical to v1.4, ERC 32 / DRC 22 both
documented, 3D coverage **183 / 183**. Everything on this page is **appearance only**.
Nothing here touches copper, and every change is gated the same way: `python3 tools/kicad-verify.py gerber
--strict` must still pass.

## Resolved

Five components rendered as an approximation or not at all. All five are now the real part,
recovered from the abandoned `migrate2kicad10` branch — see
[3D model sources](3d-model-sources.md) for the provenance table, the pad-congruence
evidence and the transform algebra.

| Ref | Was | Now |
|---|---|---|
| U26 | `Converter_DCDC_Bothhand_CFUSxxxx_THT` — wrong manufacturer, wrong body | XP Power **IZ0512S**, via the sibling IA0512S rescaled to the datasheet |
| J4 | nothing | Same Sky / CUI **SDF-80J** DIN-8, the manufacturer's own model |
| J1 | `BNC_Amphenol_B6252HB-NPP3G-50_Horizontal` — a BNC | Same Sky / CUI **RCJ-014** RCA phono |
| J5 | `..._EdgePinOffset9.40mm` — bare pins | `..._EdgePinOffset7.70mm_Housed_MountingHolesOffset9.12mm`, housing and mounting hardware |
| J2 | `BarrelJack_CUI_PJ-063AH_Horizontal` — right family, wrong part | Kycon **KLDX-0202-A** |

Three more improved along the way, because the same branch had their models too: **J3** (TE
640456-8 rather than a Molex KK-254), **SP1** (PUI AT-1224-TWT-R rather than a generic
buzzer) and **SW68** (Omron B3F-3152 rather than a PTS645).

Two things found while doing it are worth keeping:

- **U26's scale was wrong in the source branch.** The sibling-model approach was right and
  both ratios were right, but they were applied to the wrong axes — the STEP is authored
  Z-up (L × W × H) while the branch's note ordered the parts L × H × W. U26 rendered ~15.6 mm
  tall and 6.7 mm thick instead of 11.10 × 9.20. Corrected in `align_models_legacy.py`'s
  `SCALE_FIX`, so re-running reproduces the fix rather than the bug.
- **J5 does have mounting holes.** An earlier note here said the footprint had none. It has
  no *non-plated* holes, but its two 3.05 mm pads named `0` at ±12.494 are exactly the
  connector's plated mounting holes, so a housed model with mounting hardware is correct
  rather than a compromise.

## Optional: keycaps

The switches render as bare Cherry MX bodies — housing and stem, no caps. Caps would make
the render look like the finished machine, and this is the one remaining item that changes
how the board *reads* at a glance: 68 keycaps is most of the visible surface.

**No keycap models are installed anywhere** — not in KiCad's libraries, and not in the
perigoso keyswitch library, which ships only switch bodies, stabilizers and plate mounts. So
this one needs a model sourced or built first.

1. **Source or build a cap.** XDA or DSA profile, which is what skiselev recommends
   (README: *"XDA or DSA keycaps are recommended, as they have uniform shape regardless of
   the row"*). Uniform profile is a real simplification — one model serves every row.
2. **Five sizes**, matching the footprints: 1.00u (62 keys), 1.25u (SW65, SW66), 1.50u
   (SW61), 2.25u (SW11), 6.25u (SW64).
3. **Add as a second model per switch footprint**, raised to sit on the stem — the same
   composite technique the DIP sockets and stabilizers already use. Measure the Z from the
   Cherry MX drawing in `Documentation/MX Series.pdf`.
4. Run `tools/align_models.py` if the source footprint's origin differs, then
   `tools/apply_models.py`, then check the gate and look at the render.

## How to do any of this

```bash
# 1. put the sourced model where a fresh clone will find it
cp downloaded.step KiCad/Radio86RK.3dshapes/<Name>.step

# 2. add or edit its row in tools/models.tsv, referencing it via ${KIPRJMOD}
#    footprint <TAB> model <TAB> off_x <TAB> off_y <TAB> off_z <TAB> rot_z
#                              [<TAB> rot_x <TAB> rot_y <TAB> sx <TAB> sy <TAB> sz]

# 3. let a tool compute the transform rather than guessing it
python3 tools/kicad-verify.py run tools/align_models.py          # models that come from a KiCad footprint
python3 tools/kicad-verify.py run tools/align_models_legacy.py   # models from the migrate2kicad10 branch

# 4. apply, then verify
python3 tools/kicad-verify.py run tools/apply_models.py tools/models.tsv "$PCB" KiCad/Radio86RK.pretty
python3 tools/kicad-verify.py gerber          # must still PASS
python3 tools/kicad-verify.py models
python3 tools/render.py check          # and actually look at it
```

Record the model's origin and licence in `docs/3d-model-sources.md`.

**Look at the render.** Every 3D defect found in this project — the 90° IC rotation, the
half-pitch offsets, the five above, U26's swapped scale axes — was invisible to the
automated checks and obvious in a picture. Coverage proves a file resolves; it says nothing
about whether the thing looks right.

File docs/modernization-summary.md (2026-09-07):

# KiCad 10 modernization — outcome

| Metric | Before | After |
|---|---:|---:|
| Board file format | KiCad 6 (`20211014`), CRLF | KiCad 10 (`20260206`), LF |
| Schematic format | KiCad 6 (`20211123`) | KiCad 10 (`20260306`) |
| ERC violations | 243 | **32**, 0 errors, documented |
| DRC violations | 91 | **22**, 0 errors, documented |
| Unconnected items | 0 | **0** |
| Schematic/board parity | 0 | **0** |
| Components rendering in 3D | 0 / 183 | **183 / 183** |
| Gerber + drill diff vs v1.4 | — | **empty** |
| Opens from a fresh clone | no | **yes** |

## What changed on the board

**Nothing.** All 191 footprints, all copper, every drill hole and all silkscreen are
identical to skiselev's v1.4 output. The gerber and drill diff is empty, with no exception
anywhere in the project.

That is not an assertion — `python3 tools/kicad-verify.py gerber` checks it against a baseline frozen from
the board before any edit, and it was run after every one of the nine commits that touched
`KiCad/`.

The design spec had proposed one authorized copper change: adopting perigoso's Cherry MX
footprints across the keyboard, on the grounds that doing so "brings a 3D model". That
premise turned out to be false — 3D models attach to any footprint by name, and both
libraries put the switch's centre guide boss at (0, 0), so perigoso's model renders
correctly on the board's own geometry. Declining the substitution avoided a 2.286 → 2.5 mm
pad growth on 67 switches, a compensating schematic pin swap, two clearance violations at
0.150 mm, and the loss of SW11 and SW64's stabilizer holes — at a cost of nothing but
silkscreen cosmetics.

## What changed everywhere else

- **File formats** upgraded to KiCad 10 (schematics in the GUI, board via `kicad-cli`).
- **All 35 footprints vendored** from the board into `KiCad/Radio86RK.pretty`. `Cherry_MX`
  is lost upstream, so the board is the only authority for it; extracting from the board
  makes library-vs-board identity true by construction.
- **Symbols re-homed to public libraries.** Every mismatching symbol was one of KiCad's own
  stock symbols that drifted since KiCad 4, and `Device:Q_NPN_EBC` had merely moved to
  `Transistor_BJT`. Nothing needed a custom symbol.
- **`my_components` vendored** so no sibling checkout is required.
- **3D models on all 183 components**, including socket+chip composites on all 24 socketed
  DIP ICs and switch+stabilizer composites on the two wide keys. Seven parts KiCad has no
  model for — the RCA, the DIN-8, the barrel jack, the MTA header, the speaker, the tactile
  switch and the DC-DC brick — use manufacturer STEP files recovered from the abandoned
  `migrate2kicad10` branch, vendored into `KiCad/Radio86RK.3dshapes/`.

## What was deliberately not done

| | Why |
|---|---|
| 22 DRC violations | Properties of the v1.4 board. Fixing means moving silkscreen or zone geometry. See `docs/drc-exclusions.md`. |
| 32 ERC violations | Bus signals carrying both label scopes. Clearing them costs 91 label edits for 0 errors — measured, not estimated. See `docs/erc-exclusions.md`. |
| U3/U22 RS-232 defect | Pre-existing v1.4 design defect, GitHub issue #2. Fixing it is a topology change. |

## How to verify any of this yourself

```bash
python3 tools/kicad-verify.py gerber    # copper unchanged vs the frozen v1.4 baseline
python3 tools/kicad-verify.py netlist            # no pin moved to a different net
python3 tools/kicad-verify.py rules            # ERC and DRC counts by type
python3 tools/render.py mycheck  # a render into verify/renders/ (gitignored)
python3 tools/kicad-verify.py models   # 3D coverage, resolving models only
```

All of it was re-run from a fresh `git clone` into a scratch directory and produced
identical results, which is what makes "works standalone" a checked claim rather than a
hope.

## Requirements

KiCad 10.0.4, plus the **perigoso keyswitch library** installed via KiCad's Plugin and
Content Manager — that supplies the Cherry MX switch and stabilizer 3D models. Nothing else
external; all footprints and symbols the project needs are in the repository.

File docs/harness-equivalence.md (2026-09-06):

# Harness equivalence: the Python rewrite against the shell it replaced

Dated 2026-09-06. Comparison run on commit `63a7b75588a06153ef4732c37d18f9b294f62e04`
(branch `harness`), against the archived shell implementation at tag
`archive/kicad10-3d-2026-09-06` (commit `7645f3c09f3cf4c5daacfe0c9d0b797d331b8ab3`).
KiCad `10.0.4` (`kicad-cli version`), same install for both sides of every
comparison below — the shell scripts invoke it through
`$KICAD_APP/MacOS/kicad-cli` and `$KICAD_APP/Frameworks/Python.framework/.../python3.9`
(see `tools/kicad-env.sh` as archived); the Python harness invokes the same
`kicad-cli` binary via its own discovery logic. Host locale: `en_US.UTF-8`.

## Why this document exists, and why the bar is not "byte-identical"

Tasks 1–9 replaced five shell scripts (`kicad-env.sh`, `gerber_canon.py`,
`gerber-gate.sh`, `netlist-gate.sh`, `rules-report.sh`) with
`python3 tools/kicad-verify.py`, a stdlib-only Python harness. This document is
the evidence that the rewrite checks the same things the shell did — copper
geometry, connectivity, and ERC/DRC counts — not fewer, not different.

The original success bar for this task was "byte-identical output." That bar
turned out to be unattainable by design for two of the twenty-two gerber
files, and meeting it would have meant reproducing a bug rather than proving
equivalence. The archived shell gate built its strict-mode output by grepping
out the X2 net/component attribute lines and piping them through the `sort`
command:

```sh
grep -E '^%T[OA]\.' "$f" | sort >> "$out" || true
```

`sort` with no `LC_ALL` set collates under the process locale — here
`en_US.UTF-8` — which is not byte order. Python's `sorted()` on the harness
side *is* byte order. So the shell gate's own baseline was never
locale-portable: a CI runner set to `LC_ALL=C`, or any non-`en_US` locale,
would have produced a different ordering for those attribute lines than the
one committed to the repository, and reported FAIL against a change that
never happened. That is exactly the failure mode this harness exists to
prevent. The corrected bar, used below, is:

- **strict mode:** 20 of 22 files byte-identical; the remaining two hold the
  identical multiset of lines and differ only in the order of the appended
  X2 attribute block.
- **geometry mode:** 22 of 22 byte-identical (this mode drops the X2 block
  entirely, so there is nothing left for a locale to reorder).
- **netlist:** byte-identical, 5835 lines.
- **rules:** identical ERC/DRC counts and by-type breakdown.

## The decisive experiment: geometry mode isolates the cause

`gerber --geometry` and plain `gerber` (strict) run the identical export and
canonicalisation pipeline; the only difference is that geometry mode does not
append the sorted X2 attribute block at all. If the divergence in strict mode
is caused by that block's sort, geometry mode — having no sort — must
reproduce the archive with zero exceptions. It does:

```
$ python3 tools/kicad-verify.py gerber --geometry; echo "exit=$?"
[gerber] exporting gerbers
[gerber] exporting drill
[gerber] 22 files canonicalised (geometry)
error: no geometry baseline in .../verify/baseline/geometry. Run: python3 tools/kicad-verify.py baseline
exit=2
```

Exit 2 is expected and correct: geometry mode has no committed baseline in
this repository, by design (it exists only to let a legitimate net rename go
unflagged; nothing currently commits to a frozen expectation for it). The
normalised output the run just produced is still on disk. Extract the
archive's copy of `verify/baseline/geometry` (which the shell gate — run
with `--geometry --capture` at some prior point — produced) and diff:

```
$ rm -rf $SCRATCH/ag && mkdir -p $SCRATCH/ag
$ git archive archive/kicad10-3d-2026-09-06 verify/baseline/geometry \
    | tar -x -C $SCRATCH/ag --strip-components=3
$ diff -r -q $SCRATCH/ag .build/verify/gerber-geometry && echo "geometry: 22/22 identical"
geometry: 22/22 identical
```

**Result: 22/22 byte-identical.** No sort, no divergence, in all 22 files —
including the two that diverge in strict mode. This is a controlled
experiment, not just an observation: it isolates the sorted attribute block
as the sole variable and shows that removing it removes the divergence
completely.

## Strict mode: 20/22, and the two exceptions are provably cosmetic

```
$ python3 tools/kicad-verify.py gerber   # (strict is the default mode)
[gerber] exporting gerbers
[gerber] exporting drill
[gerber] 22 files canonicalised (strict)
PASS  gerber   22 files identical
```

That `PASS` is against the *committed* baseline (`verify/baseline/strict`),
which was itself captured by this Python harness (see
`verify/baseline/meta.json`, `"commit": "75e6fbe2..."`) — so it is not, by
itself, a comparison against the shell. The comparison against the shell's
own archived output is:

```
$ rm -rf $SCRATCH/as && mkdir -p $SCRATCH/as
$ git archive archive/kicad10-3d-2026-09-06 verify/baseline/strict \
    | tar -x -C $SCRATCH/as --strip-components=3
$ diff -rq $SCRATCH/as .build/verify/gerber-strict
Files .../as/Radio-86RK-B_Cu.gbl and .build/verify/gerber-strict/Radio-86RK-B_Cu.gbl differ
Files .../as/Radio-86RK-F_Cu.gtl and .build/verify/gerber-strict/Radio-86RK-F_Cu.gtl differ
```

**20 of 22 files byte-identical.** The two exceptions are exactly the two
copper layers — `Radio-86RK-B_Cu.gbl` and `Radio-86RK-F_Cu.gtl` — the layers
carrying the most net-attribute lines (6358 and 5083 lines respectively) and
therefore the only ones with enough X2 attributes for a locale-collation
reordering to be visible. Confirming the difference is ordering only, not
content:

```
$ wc -l $SCRATCH/as/Radio-86RK-B_Cu.gbl .build/verify/gerber-strict/Radio-86RK-B_Cu.gbl
    6358 .../as/Radio-86RK-B_Cu.gbl
    6358 .build/verify/gerber-strict/Radio-86RK-B_Cu.gbl
$ diff <(sort $SCRATCH/as/Radio-86RK-B_Cu.gbl) <(sort .build/verify/gerber-strict/Radio-86RK-B_Cu.gbl)
  (no output — multisets identical)
$ diff <(sort $SCRATCH/as/Radio-86RK-F_Cu.gtl) <(sort .build/verify/gerber-strict/Radio-86RK-F_Cu.gtl)
  (no output — multisets identical)
```

Same line count, same multiset of lines, in both files. Line-by-line diff
(not sorted) confirms every differing line matches `^%TO\.` — i.e. every
line that moved is an X2 net-attribute line, and nothing else in either file
is touched:

```
$ diff $SCRATCH/as/Radio-86RK-F_Cu.gtl .build/verify/gerber-strict/Radio-86RK-F_Cu.gtl \
    | grep -E '^[<>]' | sed 's/^..//' | sort -u | grep -vE '^%T'
  (no output — every differing line is a %T attribute line)
```

**0 real content differences.** The remaining two files match the corrected
success criterion exactly.

### The locale mechanism, made checkable

The shell's `sort` (no `LC_ALL`) uses the process locale's collation, which
is not byte order. This repository's shell runs under `en_US.UTF-8`. A
minimal, reproducible two-line example makes the divergence mechanical
rather than asserted:

```
$ printf '%%TO.N,+12V*%%\n%%TO.N,/~{CRT_CS}*%%\n' > $SCRATCH/mini
$ sort $SCRATCH/mini                # locale collation (en_US.UTF-8)
%TO.N,/~{CRT_CS}*%
%TO.N,+12V*%
$ LC_ALL=C sort $SCRATCH/mini        # byte order
%TO.N,+12V*%
%TO.N,/~{CRT_CS}*%
```

`en_US.UTF-8` collation gives low weight to punctuation (`/`, `~`, `{`, `}`)
in its primary comparison pass, so `/~{CRT_CS}` collates close to `CRT_CS`
and sorts ahead of `+12V`. Byte order has no such pass: `+` is `0x2B` and
`/` is `0x2F`, so `+12V` sorts first. Both orderings are internally
consistent; they are simply different total orders over the same set of
strings, and the shell gate's committed baseline can only match one of them
at a time — whichever locale captured it.

The same divergence, at full scale, on the real attribute lines extracted
from a fresh export of the board:

```
$ grep -E '^%T[OA]\.' $SCRATCH/raw/Radio-86RK-F_Cu.gtl > $SCRATCH/attrs
$ wc -l $SCRATCH/attrs
2149 .../attrs
$ sort $SCRATCH/attrs > $SCRATCH/attrs.locale
$ LC_ALL=C sort $SCRATCH/attrs > $SCRATCH/attrs.byte
$ cmp -s $SCRATCH/attrs.locale $SCRATCH/attrs.byte \
    || echo "locale sort differs from byte sort"
locale sort differs from byte sort
```

Python's `sorted()` is always byte order, regardless of the host's `LANG`
or `LC_ALL`. The rewrite's strict-mode output is therefore reproducible on
any machine, in any locale — which the archived shell gate's was not. That
is the corrected criterion's justification: byte order is the correct fix,
and the archived byte-sequence is the anomaly it corrects.

### The symmetry: the shell gate cannot reproduce the new baseline either

If the difference really is locale collation and nothing else, the shell
gate run against the (Python-authored, byte-order) committed baseline should
fail for the mirror-image reason. It does — see "Side-by-side verdicts"
below, `gerber-gate(strict)`. This is not a new bug on either side; it is the
same one-directional locale dependency observed from the other direction,
and it is recorded here because a reader who runs the shell gate against
this branch will see a FAIL and should not mistake it for a regression.

## Netlist: byte-identical, 5835 lines

```
$ python3 tools/kicad-verify.py netlist
[netlist] exporting netlist
[netlist] 5835 connectivity lines
PASS  netlist  every pin maps to the same net
```

Checked against both baselines directly:

```
$ diff .build/verify/netlist.nets verify/baseline/netlist.nets \
    && echo "netlist: byte-identical vs committed baseline"
netlist: byte-identical vs committed baseline

$ git archive archive/kicad10-3d-2026-09-06 verify/baseline/netlist.nets \
    | tar -x -C $SCRATCH/an --strip-components=2
$ diff .build/verify/netlist.nets $SCRATCH/an/netlist.nets \
    && echo "netlist: byte-identical vs archive baseline"
netlist: byte-identical vs archive baseline
$ wc -l $SCRATCH/an/netlist.nets
5835 .../netlist.nets
```

The netlist gate has no sort step and no free-ordering geometry to
canonicalise — it awks out the `(nets ...)` s-expression block and drops
`(pintype ...)` lines — so there is no locale-sensitive step to diverge on,
and none is observed: all three copies (fresh export, committed baseline,
archived baseline) are byte-identical at 5835 lines.

## Rules: same counts, different verdict shape

Shell (`tools/rules-report.sh`, extracted from the archive and run against
this tree — see "Side-by-side verdicts"):

```
ERC 413  errors=0 warnings=413
      210  footprint_link_issues
      142  lib_symbol_mismatch
       32  same_local_global_label
       29  lib_symbol_issues
DRC 212  errors=5 warnings=207
      190  lib_footprint_issues
       17  silk_edge_clearance
        5  starved_thermal
     unconnected=0  parity=0
```

Python (`python3 tools/kicad-verify.py rules`):

```
[rules] running ERC
[rules] running DRC
        ERC 413  errors=0 warnings=413
              210  footprint_link_issues
              142  lib_symbol_mismatch
               32  same_local_global_label
               29  lib_symbol_issues
        DRC 212  errors=5 warnings=207
              190  lib_footprint_issues
               17  silk_edge_clearance
                5  starved_thermal
             unconnected=0  parity=0
INFO  rules    ERC 413 (0 errors)  DRC 212 (5 errors)
```

**Identical totals, identical by-type breakdown, identical
`unconnected`/`parity` counts.** The one change is in the verdict shape, not
the numbers underneath it: the shell script was a bare report with no
pass/fail semantics at all — it printed counts and exited 0 unconditionally.
The Python harness wraps the same counts in a verdict line
(`INFO  rules    ERC 413 (0 errors)  DRC 212 (5 errors)`) and the same
`--json` document carries the full by-type breakdown as structured data
(`by_type`, `errors`, `warnings`, `total` per gate) rather than only as
human-readable text. `INFO` rather than `PASS`/`FAIL` is deliberate: the
project's ERC/DRC counts are a known, tracked baseline (413 ERC
warnings/0 errors, 212 DRC total split 190/17/5 across
`lib_footprint_issues`/`silk_edge_clearance`/`starved_thermal`) that the team
has decided not to gate the build on yet — `rules` reports drift, it does
not block on it.

## Side-by-side verdicts (shell vs Python, same tree, same commit)

The archived shell scripts were extracted to a scratch directory and copied
into `tools/` only for the duration of these runs, then removed — see
"Housekeeping" below.

| Gate | Shell (archived) | Python (`kicad-verify.py`) |
|---|---|---|
| gerber, strict | `gerber-gate(strict): FAIL` (diffs on the two copper layers' attribute order — see above) | `PASS  gerber 22 files identical` |
| gerber, geometry | `gerber-gate: no geometry baseline; run --capture` (exit 2) | `error: no geometry baseline ...` (exit 2) |
| netlist | `netlist-gate: PASS - every pin maps to the same net` | `PASS  netlist  every pin maps to the same net` |
| rules | bare report, counts above, exit 0 | `INFO  rules ERC 413 (0 errors)  DRC 212 (5 errors)`, same counts |

The shell gerber gate's FAIL against the *committed* (Python-generated,
byte-order) baseline is the mirror image of the 20/22 result above: this
repository's baseline was captured under byte order, and the shell's
locale-collated sort cannot reproduce it, for exactly the reason it could
not be reproduced in the other direction either. Both directions point at
the same cause. Every other gate agrees exactly between the two
implementations on this tree, at this commit.

### The old gate's exit code, on this same run, was not one it defines

The table above shows `gerber-gate(strict): FAIL` as printed text. The
process's actual exit code for that run was **141**, not the `1` the script
is written to return on a failed diff. The script's tail is:

```sh
if diff -r -q "$BASE" "$NORM" >/dev/null; then
  echo "gerber-gate($MODE): PASS - board geometry unchanged"
else
  echo "gerber-gate($MODE): FAIL"; diff -r -u "$BASE" "$NORM" | head -80; exit 1
fi
```

run under `set -euo pipefail` (declared near the top of the script). `head
-80` closes its input once it has printed 80 lines; on this diff there are
more than 80 lines of output, so `diff` receives `SIGPIPE` when it tries to
write past that point and is killed by that signal. Under `pipefail`, the
exit status of the pipeline is the status of the last command to fail —
`diff`'s `141` (128 + `SIGPIPE`'s signal number 13) — and `set -e` then
takes that non-zero pipeline status as the whole `if` block's result and
exits the script immediately with it, never reaching the `exit 1` written
on the same line. The printed text is correct; the process's exit code is
an accident of how much output the diff happened to produce, not a
decision anyone made.

`141` is neither `0` (pass) nor `1` (the code this script's own author
wrote for "the board changed") — it is `128 + 13`, the shell's generic
encoding for "killed by SIGPIPE," and it appears here only because this
particular failing diff happens to print more than 80 lines. A shorter
failing diff on the very same script would have returned the intended `1`;
a longer one returns `141` instead, for a reason that has nothing to do
with whether the board actually changed. A caller that only checks the
exit code — any CI step that does `gerber-gate.sh || fail-the-build` —
cannot tell "the board changed" apart from "a pipe closed early because the
failure report was long," from the same number alone. The rewrite's three
exit codes (`0` pass, `1` fail, `2` could not run — see `selftest`'s "exit
code precedence" check) exist precisely so that distinction is never left
to how much text a particular failure happens to print.

## Housekeeping performed for this comparison

- The five archived scripts (`kicad-env.sh`, `gerber_canon.py`,
  `gerber-gate.sh`, `netlist-gate.sh`, `rules-report.sh`) were copied into
  `tools/` only long enough to run them, then deleted. Confirmed removed:
  `git status --porcelain tools/` returned empty afterward.
- Neither shell script was run with `--capture`. No file under `verify/`
  was written by this comparison; `git status --porcelain verify/` shows
  only pre-existing, unrelated `.DS_Store` files, present before this task
  began.
- `.build/` is git-ignored; the shell scripts' output there (under
  `.build/gerber-strict`, `.build/netlist.nets`, etc., alongside the
  Python harness's own `.build/verify/...` tree) is not tracked and needed
  no cleanup.

## Full run, clean tree

```
$ git stash list                      # pre-existing stashes from unrelated work; none added or touched by this task
$ rm -rf .build
$ python3 tools/kicad-verify.py selftest
...
PASS  selftest 21 checks passed
```

(An earlier planning note for this rewrite predicted 17 self-test checks;
that number predates later additions to the harness's self-test suite —
version-drift detection, JSON mode, and the `all`-command's exit-code
precedence among them. 21 is the current, correct count, not a discrepancy.)

```
$ python3 tools/kicad-verify.py all
[gerber] exporting gerbers
[gerber] exporting drill
[gerber] 22 files canonicalised (strict)
[netlist] exporting netlist
[netlist] 5835 connectivity lines
[rules] running ERC
[rules] running DRC
        ERC 413  errors=0 warnings=413
              210  footprint_link_issues
              142  lib_symbol_mismatch
               32  same_local_global_label
               29  lib_symbol_issues
        DRC 212  errors=5 warnings=207
              190  lib_footprint_issues
               17  silk_edge_clearance
                5  starved_thermal
             unconnected=0  parity=0
PASS  gerber   22 files identical
PASS  netlist  every pin maps to the same net
INFO  rules    ERC 413 (0 errors)  DRC 212 (5 errors)
PASS  all      3 of 3 gates passed
exit=0
```

## Conclusion

- **Geometry** (22/22): identical, with no locale-sensitive step anywhere in
  the pipeline to explain a divergence if one had appeared.
- **Strict** (20/22, 0 real content differences): the two exceptions are the
  two copper layers, and their only difference is the order of the X2
  attribute block a locale-sensitive `sort` produced in the shell and a
  byte-order `sorted()` produces in Python — demonstrated directly, at both
  minimal and full scale, above.
- **Netlist**: byte-identical, 5835 lines, against both the committed and
  the archived baseline.
- **Rules**: identical counts and identical by-type breakdown between the
  shell report and the Python `INFO` verdict; only the presentation
  changed, from an unconditional bare report to a verdict line with the
  same numbers underneath and a structured JSON form.

The rewrite does not change what is being checked. Where its output differs
from the archived shell's, the difference is exactly one locale-dependent
sort order that carried no information to begin with, and the harness's
byte-order replacement is the more reproducible of the two.

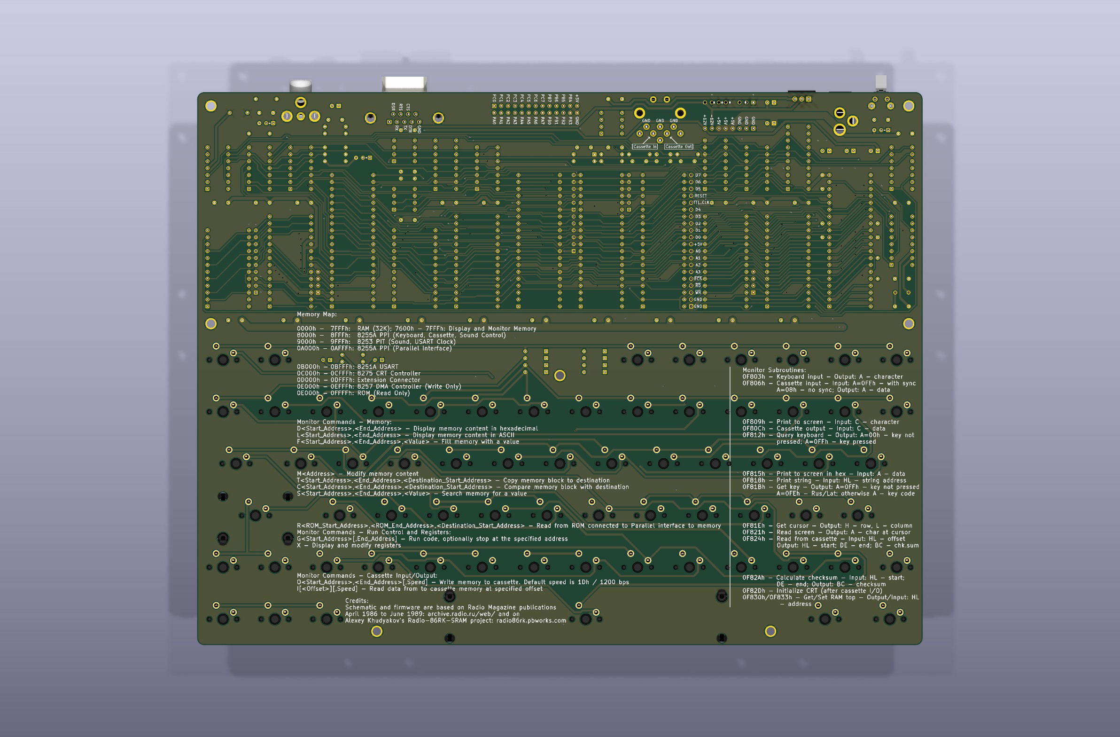
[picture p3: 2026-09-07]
images/Radio-86RK-1.4-3D-Bottom.jpg

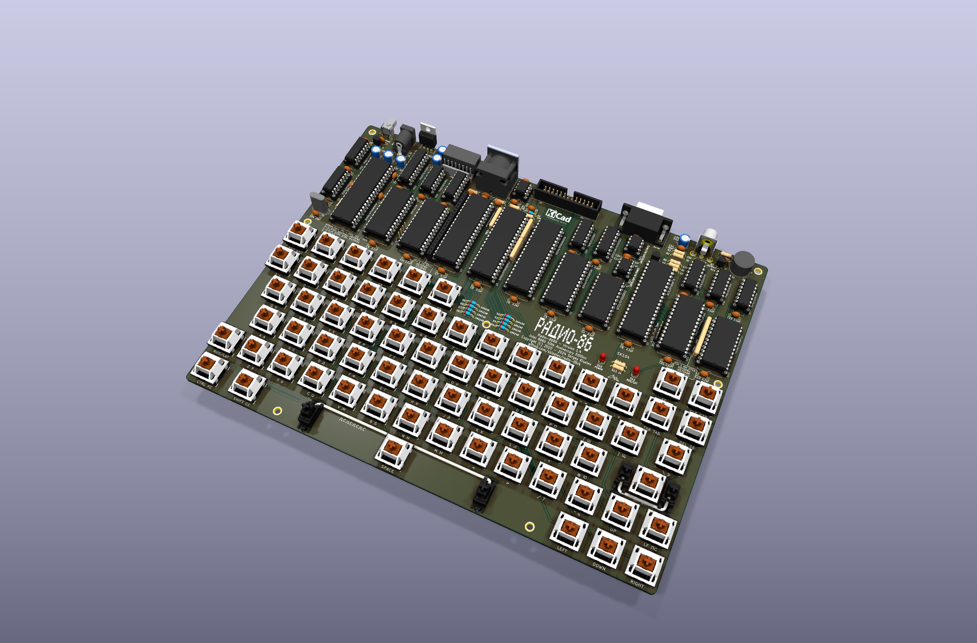
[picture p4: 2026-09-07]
images/Radio-86RK-1.4-3D-Iso-Right.jpg

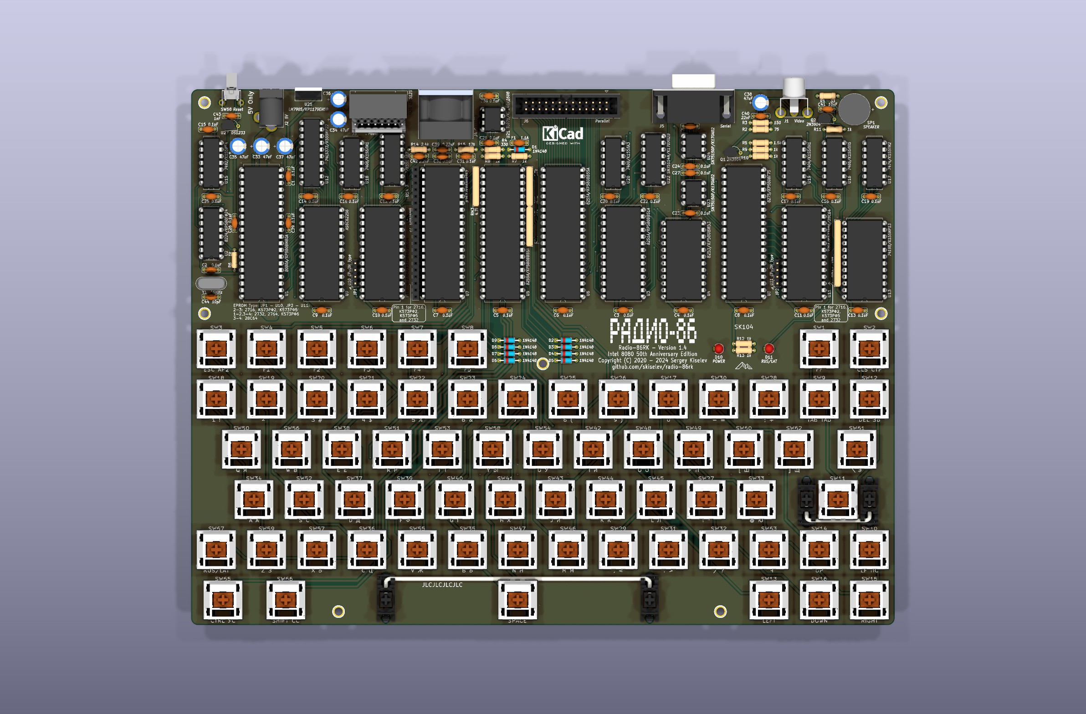
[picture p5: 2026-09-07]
images/Radio-86RK-1.4-3D-Top.jpg

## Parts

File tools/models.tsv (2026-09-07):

# footprint | model | off_x | off_y | off_z | rot_z | [rot_x | rot_y | sx | sy | sz]
# Offsets and rotations are computed by tools/align_models.py: KiCad models are
# authored in KiCad's own footprint frame, ours use different conventions.
Res_762 | ${KICAD10_3DMODEL_DIR}/Resistor_THT.3dshapes/R_Axial_DIN0207_L6.3mm_D2.5mm_P7.62mm_Horizontal.step | -3.81 | 0 | 0 | 0
Cap_Cer_508 | ${KICAD10_3DMODEL_DIR}/Capacitor_THT.3dshapes/C_Disc_D5.0mm_W2.5mm_P5.00mm.step | -2.54 | 0 | 0 | 0
Cap_Elec_Radial_6.3mm | ${KICAD10_3DMODEL_DIR}/Capacitor_THT.3dshapes/CP_Radial_D6.3mm_P2.50mm.step | -1.25 | 0 | 0 | 0
Diode_762 | ${KICAD10_3DMODEL_DIR}/Diode_THT.3dshapes/D_DO-35_SOD27_P7.62mm_Horizontal.step | 3.81 | 0 | 0 | 180
LED_3mm | ${KICAD10_3DMODEL_DIR}/LED_THT.3dshapes/LED_D3.0mm.step | 1.27 | 0 | 0 | 180
Crystal_HC-49U_Vert | ${KICAD10_3DMODEL_DIR}/Crystal.3dshapes/Crystal_HC49-U_Vertical.step | -2.4409 | 0 | 0 | 0
Transistor_TO92_EBC_254 | ${KICAD10_3DMODEL_DIR}/Package_TO_SOT_THT.3dshapes/TO-92_Inline.step | -2.54 | 0 | 0 | 0
IC_TO220-3_Vert | ${KICAD10_3DMODEL_DIR}/Package_TO_SOT_THT.3dshapes/TO-220-3_Vertical.step | -2.54 | 0 | 0 | 0
IC_DIP8_300 | ${KICAD10_3DMODEL_DIR}/Package_DIP.3dshapes/DIP-8_W7.62mm_Socket.step | -3.81 | -3.81 | 0 | 270
IC_DIP8_300 | ${KICAD10_3DMODEL_DIR}/Package_DIP.3dshapes/DIP-8_W7.62mm.step | -3.81 | -3.81 | 5.1 | 270
IC_DIP14_300 | ${KICAD10_3DMODEL_DIR}/Package_DIP.3dshapes/DIP-14_W7.62mm_Socket.step | -7.62 | -3.81 | 0 | 270
IC_DIP14_300 | ${KICAD10_3DMODEL_DIR}/Package_DIP.3dshapes/DIP-14_W7.62mm.step | -7.62 | -3.81 | 5.48 | 270
IC_DIP16_300 | ${KICAD10_3DMODEL_DIR}/Package_DIP.3dshapes/DIP-16_W7.62mm_Socket.step | -8.89 | -3.81 | 0 | 270
IC_DIP16_300 | ${KICAD10_3DMODEL_DIR}/Package_DIP.3dshapes/DIP-16_W7.62mm.step | -8.89 | -3.81 | 5.48 | 270
IC_DIP20_300 | ${KICAD10_3DMODEL_DIR}/Package_DIP.3dshapes/DIP-20_W7.62mm_Socket.step | -11.43 | -3.81 | 0 | 270
IC_DIP20_300 | ${KICAD10_3DMODEL_DIR}/Package_DIP.3dshapes/DIP-20_W7.62mm.step | -11.43 | -3.81 | 5.48 | 270
IC_DIP24_600 | ${KICAD10_3DMODEL_DIR}/Package_DIP.3dshapes/DIP-24_W15.24mm_Socket.step | -13.97 | -7.62 | 0 | 270
IC_DIP24_600 | ${KICAD10_3DMODEL_DIR}/Package_DIP.3dshapes/DIP-24_W15.24mm.step | -13.97 | -7.62 | 5.48 | 270
IC_DIP28_600 | ${KICAD10_3DMODEL_DIR}/Package_DIP.3dshapes/DIP-28_W15.24mm_Socket.step | -16.51 | -7.62 | 0 | 270
IC_DIP28_600 | ${KICAD10_3DMODEL_DIR}/Package_DIP.3dshapes/DIP-28_W15.24mm.step | -16.51 | -7.62 | 5.48 | 270
IC_DIP40_600 | ${KICAD10_3DMODEL_DIR}/Package_DIP.3dshapes/DIP-40_W15.24mm_Socket.step | -24.13 | -7.62 | 0 | 270
IC_DIP40_600 | ${KICAD10_3DMODEL_DIR}/Package_DIP.3dshapes/DIP-40_W15.24mm.step | -24.13 | -7.62 | 5.48 | 270
Conn_SIL6 | ${KICAD10_3DMODEL_DIR}/Resistor_THT.3dshapes/R_Array_SIP6.step | -6.35 | 0 | 0 | 0
Conn_SIL10 | ${KICAD10_3DMODEL_DIR}/Resistor_THT.3dshapes/R_Array_SIP10.step | -11.43 | 0 | 0 | 0
Conn_Pin_Header_4x1_2.54mm | ${KICAD10_3DMODEL_DIR}/Connector_PinHeader_2.54mm.3dshapes/PinHeader_1x04_P2.54mm_Vertical.step | -3.81 | 0 | 0 | 270
Conn_Pin_Header_20x1_2.54mm | ${KICAD10_3DMODEL_DIR}/Connector_PinSocket_2.54mm.3dshapes/PinSocket_1x20_P2.54mm_Vertical.step | -24.13 | 0 | 0 | 270
Conn_Pin_Header_13x2_2.54mm_Shrouded | ${KICAD10_3DMODEL_DIR}/Connector_IDC.3dshapes/IDC-Header_2x13_P2.54mm_Vertical.step | -15.24 | -1.27 | 0 | 270
Conn_Friction_Lock_8P_2.54mm | ${KIPRJMOD}/Radio86RK.3dshapes/640456-8.step | -0.0200 | -0.4600 | 2.5400 | 180.0000 | 0.0000 | 0.0000 | 1.0000 | 1.0000 | 1.0000
Conn_Power_Jack_Circular_Pads | ${KIPRJMOD}/Radio86RK.3dshapes/KLDX-0202-A.step | -7.7999 | -0.1900 | 6.7400 | 90.0000 | -90.0000 | 0.0000 | 1.0000 | 1.0000 | 1.0000
Conn_Dsub_DE9M | ${KICAD10_3DMODEL_DIR}/Connector_Dsub.3dshapes/DSUB-9_Pins_Horizontal_P2.77x2.84mm_EdgePinOffset7.70mm_Housed_MountingHolesOffset9.12mm.step | 5.4864 | -1.4224 | 0 | 180
Speaker_12mm | ${KIPRJMOD}/Radio86RK.3dshapes/AT-1224-TWT-R.step | 3.2512 | 0.0000 | 0.0000 | 90.0000 | 0.0000 | 0.0000 | 1.0000 | 1.0000 | 1.0000
DC-DC_SIP8 | ${KIPRJMOD}/Radio86RK.3dshapes/IZ0512S.step | -8.8900 | 0.0000 | 0.0000 | 0.0000 | 0.0000 | 0.0000 | 1.1321 | 1.5107 | 1.0925
Conn_RCA_Right | ${KIPRJMOD}/Radio86RK.3dshapes/RCJ-014.step | 6.0800 | 0.0000 | 7.0000 | 180.0000 | -90.0000 | 0.0000 | 1.0000 | 1.0000 | 1.0000
Switch_Tactile_6mm_Right | ${KIPRJMOD}/Radio86RK.3dshapes/B3F-3152.step | -2.2470 | -3.8806 | -0.0100 | 180.0000 | -90.0000 | 0.0000 | 1.0000 | 1.0000 | 1.0000
# --- Keyboard: verified correct at offset 0; origins coincide with perigoso's ---
CHERRY_PCB_100H | ${KICAD10_3RD_PARTY}/3dmodels/com_github_perigoso_keyswitch-kicad-library/3d-library.3dshapes/SW_Cherry_MX_PCB.stp | 0 | 0 | 0 | 0
CHERRY_PCB_125H | ${KICAD10_3RD_PARTY}/3dmodels/com_github_perigoso_keyswitch-kicad-library/3d-library.3dshapes/SW_Cherry_MX_PCB.stp | 0 | 0 | 0 | 0
CHERRY_PCB_150H | ${KICAD10_3RD_PARTY}/3dmodels/com_github_perigoso_keyswitch-kicad-library/3d-library.3dshapes/SW_Cherry_MX_PCB.stp | 0 | 0 | 0 | 0
CHERRY_PCB_225H | ${KICAD10_3RD_PARTY}/3dmodels/com_github_perigoso_keyswitch-kicad-library/3d-library.3dshapes/SW_Cherry_MX_PCB.stp | 0 | 0 | 0 | 0
CHERRY_PCB_225H | ${KICAD10_3RD_PARTY}/3dmodels/com_github_perigoso_keyswitch-kicad-library/3d-library.3dshapes/Stabilizer_Cherry_MX_2.00u.stp | 0 | 0 | 0 | 0
CHERRY_PCB_625H | ${KICAD10_3RD_PARTY}/3dmodels/com_github_perigoso_keyswitch-kicad-library/3d-library.3dshapes/SW_Cherry_MX_PCB.stp | 0 | 0 | 0 | 0
CHERRY_PCB_625H | ${KICAD10_3RD_PARTY}/3dmodels/com_github_perigoso_keyswitch-kicad-library/3d-library.3dshapes/Stabilizer_Cherry_MX_6.25u.stp | 0 | 0 | 0 | 180
# --- Manufacturer models recovered from the migrate2kicad10 branch ---
# (rows are above, next to their neighbours; regenerate with tools/align_models_legacy.py)
Conn_DIN_8pin | ${KIPRJMOD}/Radio86RK.3dshapes/SDF-80J.step | -0.0100 | -7.7500 | 0.0600 | 180.0000 | -90.0000 | 0.0000 | 1.0000 | 1.0000 | 1.0000

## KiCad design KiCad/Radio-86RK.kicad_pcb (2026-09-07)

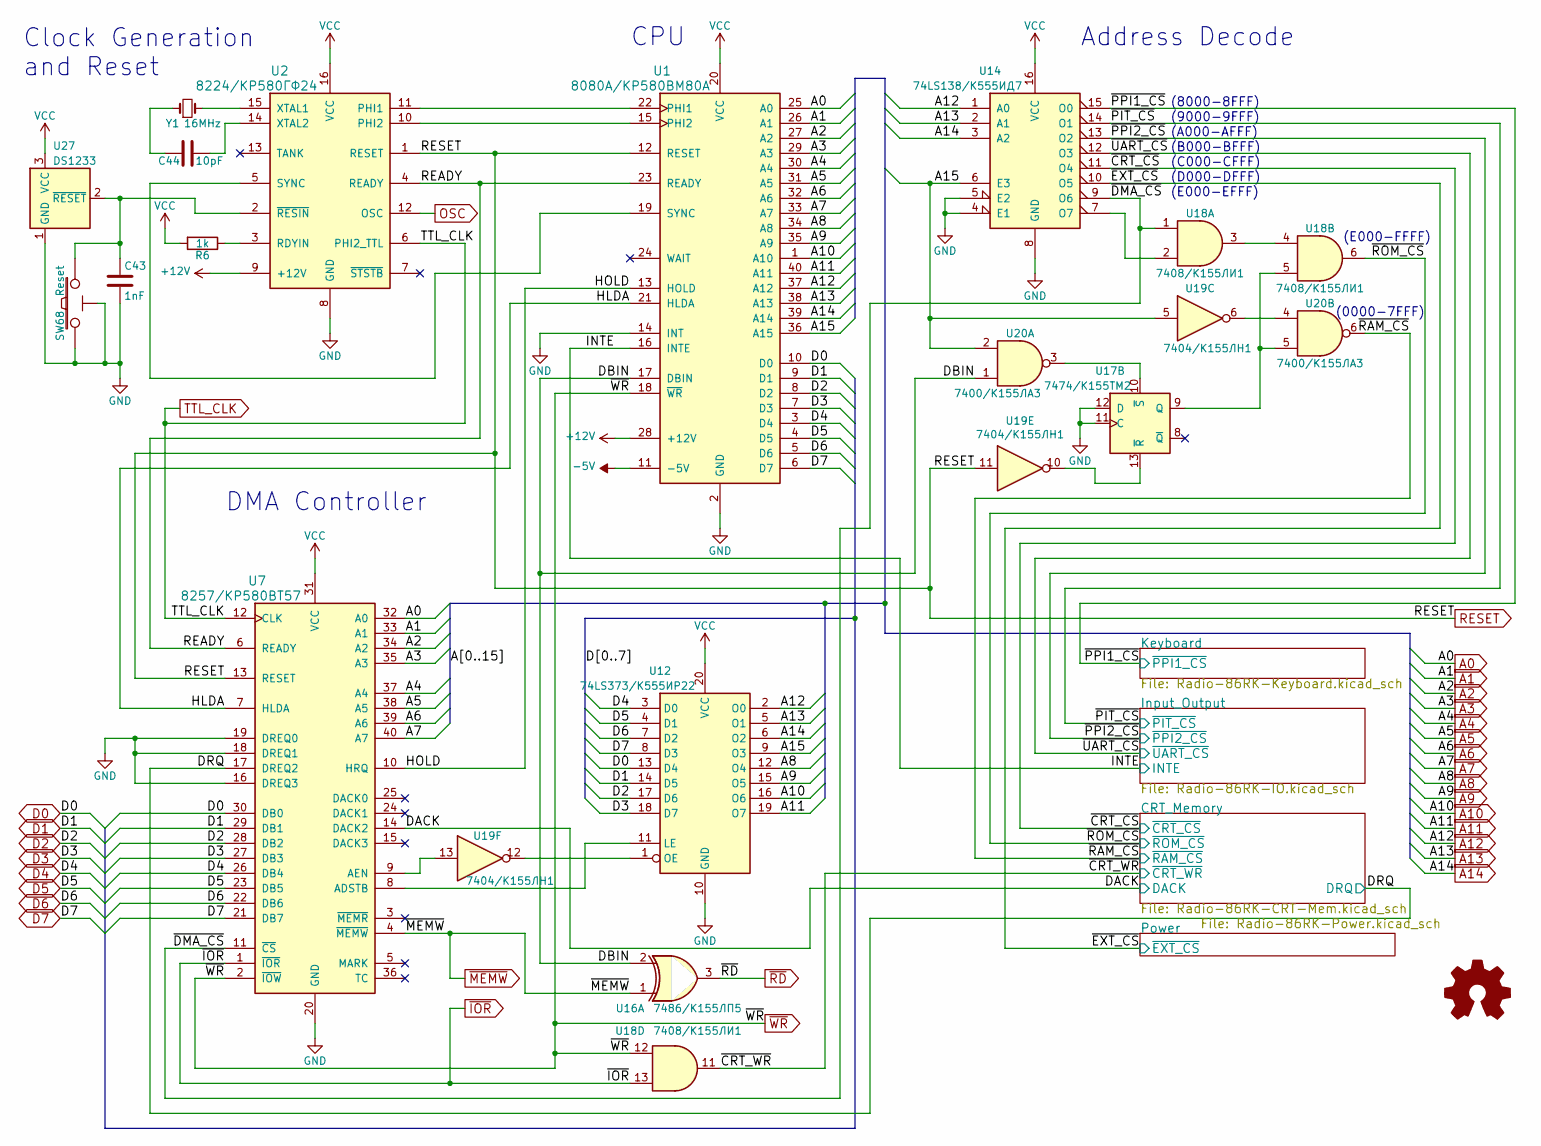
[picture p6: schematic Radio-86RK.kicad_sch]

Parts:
C43: 1nF; Cap_Cer_508
C44: 10pF; Cap_Cer_508
LOGO1: Logo_Open_Hardware_Small; KiCad-Logo2_6mm_SilkScreen
R6: 1k; Res_762
SW68: Reset; Switch_Tactile_6mm_Right
U1: 8080A/КР580ВМ80А; IC_DIP40_600
U2: 8224/КР580ГФ24; IC_DIP16_300
U7: 8257/КР580ВТ57; IC_DIP40_600
U12: 74LS373/К555ИР22; IC_DIP20_300
U14: 74LS138/К555ИД7; IC_DIP16_300
U16: 7486/К155ЛП5; IC_DIP14_300
U17: 7474/К155ТМ2; IC_DIP14_300
U18: 7408/К155ЛИ1; IC_DIP14_300
U19: 7404/К155ЛН1; IC_DIP14_300
U20: 7400/К155ЛА3; IC_DIP14_300
U27: DS1233; Transistor_TO92_EBC_254
Y1: 16MHz; Crystal_HC-49U_Vert

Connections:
+12V: U1.28 (+12V), U2.9 (+12V); also elsewhere on the board
-5V: U1.11 (-5V); also elsewhere on the board
/A15: U1.36 (A15), U12.9 (O3), U14.6 (E3), U19.5, U20.2
/DACK: U7.14 (DACK2); also elsewhere on the board
/DBIN: U1.17 (DBIN), U16.2, U20.1
/DRQ: U7.17 (DREQ2); also elsewhere on the board
/HLDA: U1.21 (HLDA), U7.7 (HLDA)
/HOLD: U1.13 (HOLD), U7.10 (HRQ)
/INTE: U1.16 (INTE); also elsewhere on the board
/READY: U1.23 (READY), U2.4 (READY), U7.6 (READY)
/~CRT_CS: U14.11 (O4); also elsewhere on the board
/~CRT_WR: U18.11; also elsewhere on the board
/~DMA_CS: U7.11 (~CS), U14.9 (O6), U18.1
/~EXT_CS: U14.10 (O5); also elsewhere on the board
/~PIT_CS: U14.14 (O1); also elsewhere on the board
/~PPI1_CS: U14.15 (O0); also elsewhere on the board
/~PPI2_CS: U14.13 (O2); also elsewhere on the board
/~RAM_CS: U20.6; also elsewhere on the board
/~ROM_CS: U18.6; also elsewhere on the board
/~UART_CS: U14.12 (O3); also elsewhere on the board
A0: U1.25 (A0), U7.32 (A0); also elsewhere on the board
A1: U1.26 (A1), U7.33 (A1); also elsewhere on the board
A2: U1.27 (A2), U7.34 (A2); also elsewhere on the board
A3: U1.29 (A3), U7.35 (A3); also elsewhere on the board
A4: U1.30 (A4), U7.37 (A4); also elsewhere on the board
A5: U1.31 (A5), U7.38 (A5); also elsewhere on the board
A6: U1.32 (A6), U7.39 (A6); also elsewhere on the board
A7: U1.33 (A7), U7.40 (A7); also elsewhere on the board
A8: U1.34 (A8), U12.12 (O4); also elsewhere on the board
A9: U1.35 (A9), U12.15 (O5); also elsewhere on the board
A10: U1.1 (A10), U12.16 (O6); also elsewhere on the board
A11: U1.40 (A11), U12.19 (O7); also elsewhere on the board
A12: U1.37 (A12), U12.2 (O0), U14.1 (A0); also elsewhere on the board
A13: U1.38 (A13), U12.5 (O1), U14.2 (A1); also elsewhere on the board
A14: U1.39 (A14), U12.6 (O2), U14.3 (A2); also elsewhere on the board
D0: U1.10 (D0), U7.30 (DB0), U12.13 (D4); also elsewhere on the board
D1: U1.9 (D1), U7.29 (DB1), U12.14 (D5); also elsewhere on the board
D2: U1.8 (D2), U7.28 (DB2), U12.17 (D6); also elsewhere on the board
D3: U1.7 (D3), U7.27 (DB3), U12.18 (D7); also elsewhere on the board
D4: U1.3 (D4), U7.26 (DB4), U12.3 (D0); also elsewhere on the board
D5: U1.4 (D5), U7.23 (DB5), U12.4 (D1); also elsewhere on the board
D6: U1.5 (D6), U7.22 (DB6), U12.7 (D2); also elsewhere on the board
D7: U1.6 (D7), U7.21 (DB7), U12.8 (D3); also elsewhere on the board
GND: C43.2, SW68.2, SW68.GND, U1.2 (GND), U1.14 (INT), U2.8 (GND), U7.16 (DREQ3), U7.18 (DREQ1), U7.19 (DREQ0), U7.20 (GND), U12.10 (GND), U14.4 (E1), U14.5 (E2), U14.8 (GND), U17.11 (C), U17.12 (D), U27.1 (GND); also elsewhere on the board
unnamed: C43.1, SW68.1, U2.2 (~RESIN), U27.2 (~RESET)
unnamed: C44.1, U2.14 (XTAL2)
unnamed: C44.2, Y1.1
unnamed: R6.1, U2.3 (RDYIN)
unnamed: U1.15 (PHI2), U2.10 (PHI2)
unnamed: U1.19 (SYNC), U2.5 (SYNC)
unnamed: U1.22 (PHI1), U2.11 (PHI1)
unnamed: U2.15 (XTAL1), Y1.2
unnamed: U12.1 (OE), U19.12
unnamed: U7.8 (ADSTB), U12.11 (LE)
unnamed: U14.7 (O7), U18.2
unnamed: U17.9 (Q), U18.5, U20.5
unnamed: U17.10 (~S), U20.3
unnamed: U17.13 (~R), U19.10
unnamed: U18.3, U18.4
unnamed: U19.6, U20.4
unnamed: U7.9 (AEN), U19.13
OSC: U2.12 (OSC); also elsewhere on the board
RESET: U1.12 (RESET), U2.1 (RESET), U7.13 (RESET), U19.11; also elsewhere on the board
TTL_CLK: U2.6 (PHI2_TTL), U7.12 (CLK); also elsewhere on the board
VCC: R6.2, U1.20 (VCC), U2.16 (VCC), U7.31 (VCC), U12.20 (VCC), U14.16 (VCC), U27.3 (VCC); also elsewhere on the board
~IOR: U7.1 (~IOR), U18.13; also elsewhere on the board
~MEMW: U7.4 (~MEMW), U16.1; also elsewhere on the board
~RD: U16.3; also elsewhere on the board
~WR: U1.18 (~WR), U7.2 (~IOW), U18.12; also elsewhere on the board

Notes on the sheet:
CPU
(E000-FFFF)
(8000-8FFF)
Clock Generation and Reset
(B000-BFFF)
(C000-CFFF)
(0000-7FFF)
(9000-9FFF)
Address Decode
(E000-EFFF)
(A000-AFFF)
DMA Controller
(D000-DFFF)

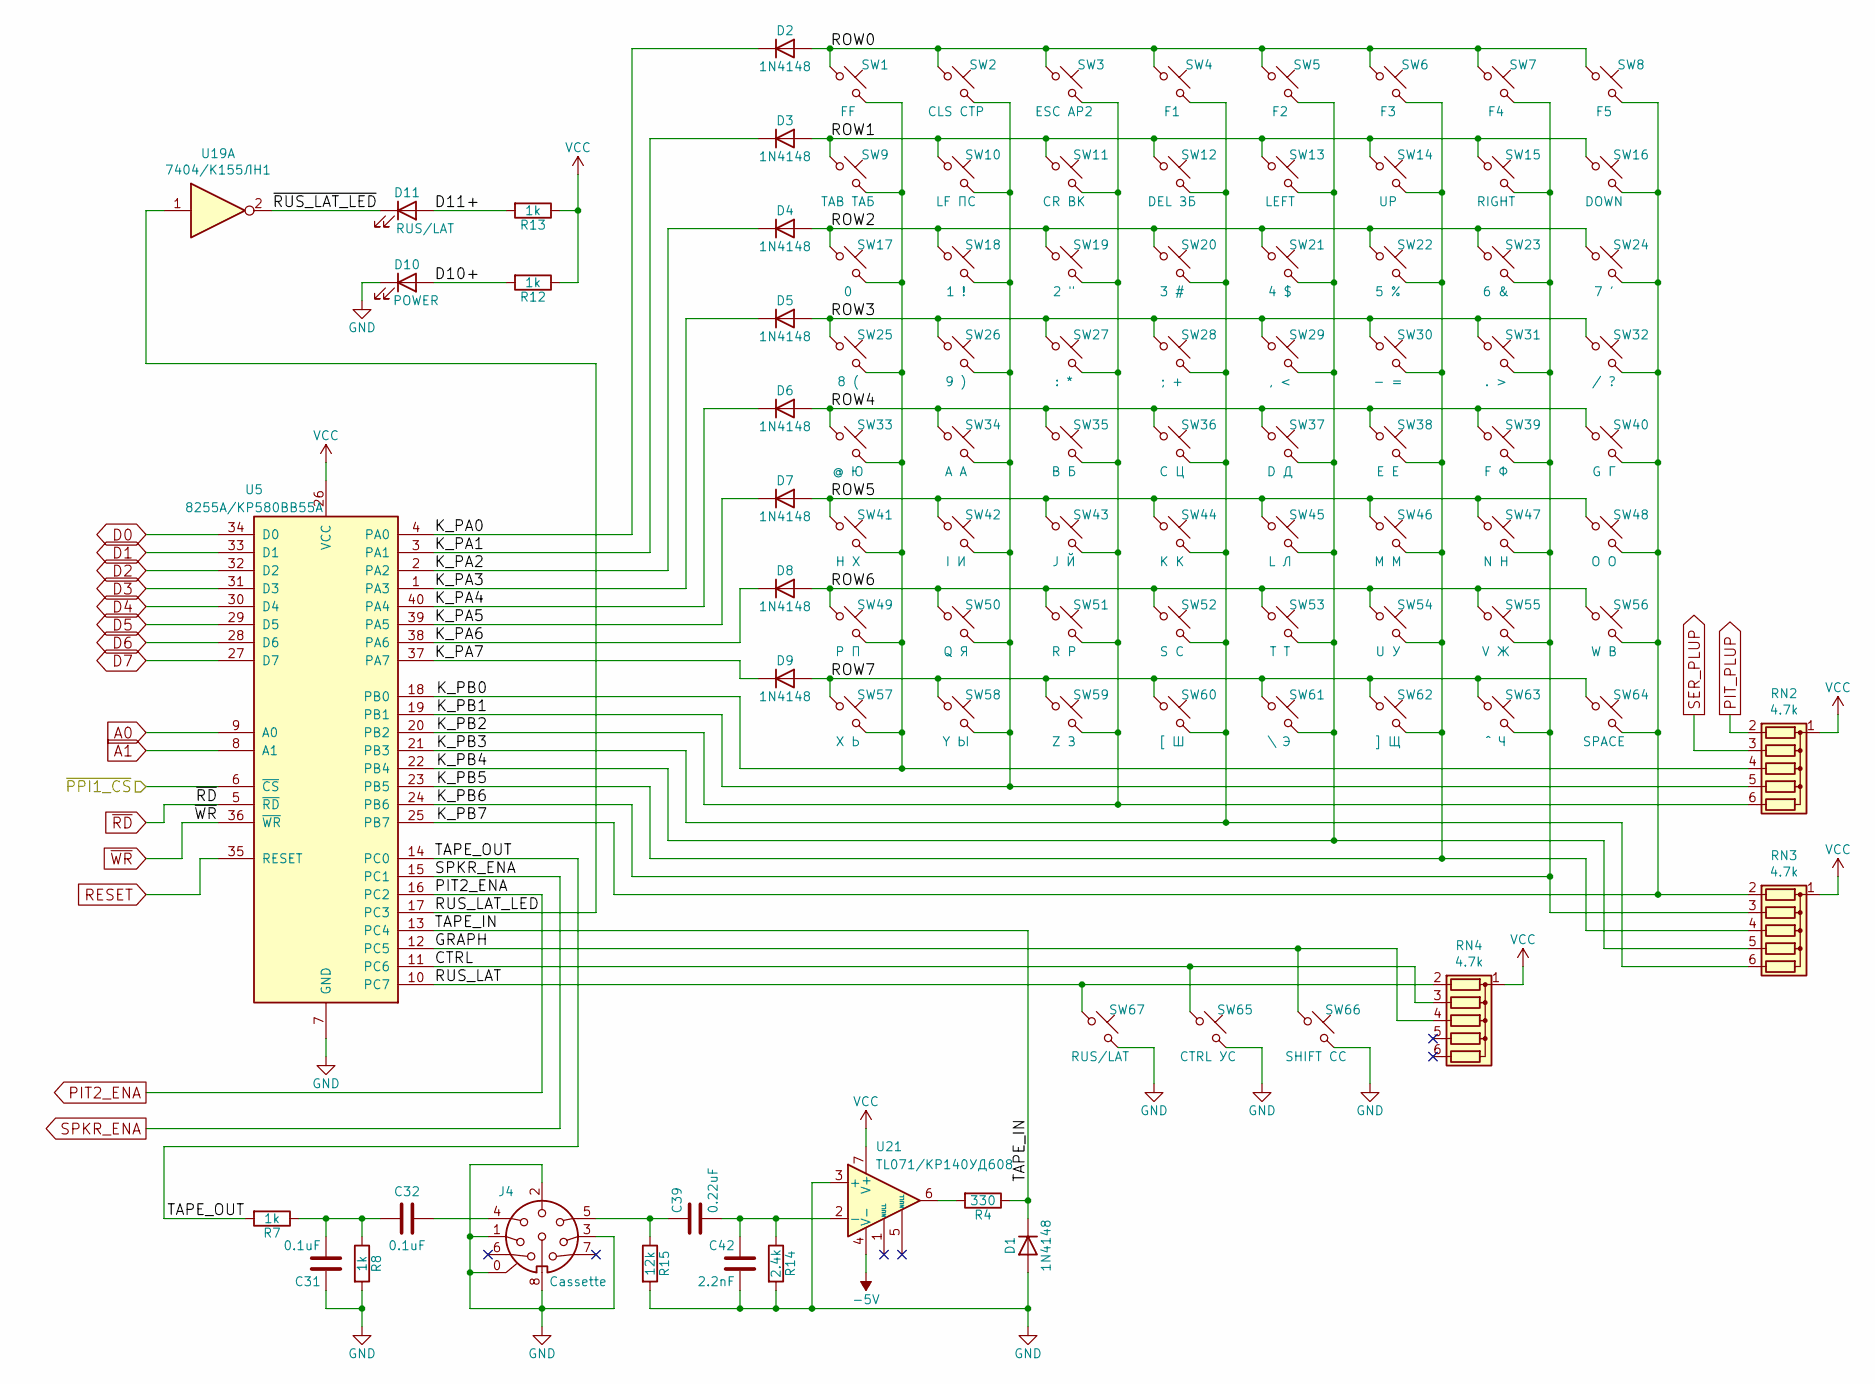
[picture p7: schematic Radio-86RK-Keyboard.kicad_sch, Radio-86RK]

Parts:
C31, C32: 0.1uF; Cap_Cer_508
C39: 0.22uF; Cap_Cer_508
C42: 2.2nF; Cap_Cer_508
D1, D2, D3, D4, D5, D6, D7, D8, D9: 1N4148; Diode_762
D10: POWER; LED_3mm
D11: RUS/LAT; LED_3mm
J4: Cassette; Conn_DIN_8pin
R4: 330; Res_762
R7, R8, R12, R13: 1k; Res_762
R14: 2.4k; Res_762
R15: 12k; Res_762
RN2, RN3, RN4: 4.7k; Conn_SIL6
SW1: FF; CHERRY_PCB_100H
SW2: CLS СТР; CHERRY_PCB_100H
SW3: ESC АР2; CHERRY_PCB_100H
SW4: F1; CHERRY_PCB_100H
SW5: F2; CHERRY_PCB_100H
SW6: F3; CHERRY_PCB_100H
SW7: F4; CHERRY_PCB_100H
SW8: F5; CHERRY_PCB_100H
SW9: TAB ТАБ; CHERRY_PCB_100H
SW10: LF ПС; CHERRY_PCB_100H
SW11: CR ВК; CHERRY_PCB_225H
SW12: DEL ЗБ; CHERRY_PCB_100H
SW13: LEFT; CHERRY_PCB_100H
SW14: UP; CHERRY_PCB_100H
SW15: RIGHT; CHERRY_PCB_100H
SW16: DOWN; CHERRY_PCB_100H
SW17: 0; CHERRY_PCB_100H
SW18: 1 !; CHERRY_PCB_100H
SW19: 2 "; CHERRY_PCB_100H
SW20: 3 #; CHERRY_PCB_100H
SW21: 4 $; CHERRY_PCB_100H
SW22: 5 %; CHERRY_PCB_100H
SW23: 6 &; CHERRY_PCB_100H
SW24: 7 '; CHERRY_PCB_100H
SW25: 8 (; CHERRY_PCB_100H
SW26: 9 ); CHERRY_PCB_100H
SW27: : *; CHERRY_PCB_100H
SW28: ; +; CHERRY_PCB_100H
SW29: , <; CHERRY_PCB_100H
SW30: - =; CHERRY_PCB_100H
SW31: . >; CHERRY_PCB_100H
SW32: / ?; CHERRY_PCB_100H
SW33: @ Ю; CHERRY_PCB_100H
SW34: A А; CHERRY_PCB_100H
SW35: B Б; CHERRY_PCB_100H
SW36: C Ц; CHERRY_PCB_100H
SW37: D Д; CHERRY_PCB_100H
SW38: E Е; CHERRY_PCB_100H
SW39: F Ф; CHERRY_PCB_100H
SW40: G Г; CHERRY_PCB_100H
SW41: H Х; CHERRY_PCB_100H
SW42: I И; CHERRY_PCB_100H
SW43: J Й; CHERRY_PCB_100H
SW44: K К; CHERRY_PCB_100H
SW45: L Л; CHERRY_PCB_100H
SW46: M М; CHERRY_PCB_100H
SW47: N Н; CHERRY_PCB_100H
SW48: O О; CHERRY_PCB_100H
SW49: P П; CHERRY_PCB_100H
SW50: Q Я; CHERRY_PCB_100H
SW51: R Р; CHERRY_PCB_100H
SW52: S С; CHERRY_PCB_100H
SW53: T Т; CHERRY_PCB_100H
SW54: U У; CHERRY_PCB_100H
SW55: V Ж; CHERRY_PCB_100H
SW56: W В; CHERRY_PCB_100H
SW57: X Ь; CHERRY_PCB_100H
SW58: Y Ы; CHERRY_PCB_100H
SW59: Z З; CHERRY_PCB_100H
SW60: [ Ш; CHERRY_PCB_100H
SW61: \ Э; CHERRY_PCB_150H
SW62: ] Щ; CHERRY_PCB_100H
SW63: ^ Ч; CHERRY_PCB_100H
SW64: SPACE; CHERRY_PCB_625H
SW65: CTRL УС; CHERRY_PCB_125H
SW66: SHIFT CC; CHERRY_PCB_125H
SW67: RUS/LAT; CHERRY_PCB_100H
U5: 8255A/КР580ВВ55А; IC_DIP40_600
U19: 7404/К155ЛН1; IC_DIP14_300
U21: TL071/КР140УД608; IC_DIP8_300

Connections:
-5V: U21.4 (V-); also elsewhere on the board
/Keyboard/CTRL: RN4.3 (R2), SW65.1, U5.11 (PC6)
/Keyboard/D10+: D10.2 (A), R12.2
/Keyboard/D11+: D11.2 (A), R13.2
/Keyboard/GRAPH: RN4.4 (R3), SW66.1, U5.12 (PC5)
/Keyboard/K_PA0: D2.1 (K), U5.4 (PA0)
/Keyboard/K_PA1: D3.1 (K), U5.3 (PA1)
/Keyboard/K_PA2: D4.1 (K), U5.2 (PA2)
/Keyboard/K_PA3: D5.1 (K), U5.1 (PA3)
/Keyboard/K_PA4: D6.1 (K), U5.40 (PA4)
/Keyboard/K_PA5: D7.1 (K), U5.39 (PA5)
/Keyboard/K_PA6: D8.1 (K), U5.38 (PA6)
/Keyboard/K_PA7: D9.1 (K), U5.37 (PA7)
/Keyboard/K_PB0: RN2.4 (R3), SW1.2, SW9.2, SW17.2, SW25.2, SW33.2, SW41.2, SW49.2, SW57.2, U5.18 (PB0)
/Keyboard/K_PB1: RN2.5 (R4), SW2.2, SW10.2, SW18.2, SW26.2, SW34.2, SW42.2, SW50.2, SW58.2, U5.19 (PB1)
/Keyboard/K_PB2: RN2.6 (R5), SW3.2, SW11.2, SW19.2, SW27.2, SW35.2, SW43.2, SW51.2, SW59.2, U5.20 (PB2)
/Keyboard/K_PB3: RN3.6 (R5), SW4.2, SW12.2, SW20.2, SW28.2, SW36.2, SW44.2, SW52.2, SW60.2, U5.21 (PB3)
/Keyboard/K_PB4: RN3.5 (R4), SW5.2, SW13.2, SW21.2, SW29.2, SW37.2, SW45.2, SW53.2, SW61.2, U5.22 (PB4)
/Keyboard/K_PB5: RN3.4 (R3), SW6.2, SW14.2, SW22.2, SW30.2, SW38.2, SW46.2, SW54.2, SW62.2, U5.23 (PB5)
/Keyboard/K_PB6: RN3.3 (R2), SW7.2, SW15.2, SW23.2, SW31.2, SW39.2, SW47.2, SW55.2, SW63.2, U5.24 (PB6)
/Keyboard/K_PB7: RN3.2 (R1), SW8.2, SW16.2, SW24.2, SW32.2, SW40.2, SW48.2, SW56.2, SW64.2, U5.25 (PB7)
/Keyboard/ROW0: D2.2 (A), SW1.1, SW2.1, SW3.1, SW4.1, SW5.1, SW6.1, SW7.1, SW8.1
/Keyboard/ROW1: D3.2 (A), SW9.1, SW10.1, SW11.1, SW12.1, SW13.1, SW14.1, SW15.1, SW16.1
/Keyboard/ROW2: D4.2 (A), SW17.1, SW18.1, SW19.1, SW20.1, SW21.1, SW22.1, SW23.1, SW24.1
/Keyboard/ROW3: D5.2 (A), SW25.1, SW26.1, SW27.1, SW28.1, SW29.1, SW30.1, SW31.1, SW32.1
/Keyboard/ROW4: D6.2 (A), SW33.1, SW34.1, SW35.1, SW36.1, SW37.1, SW38.1, SW39.1, SW40.1
/Keyboard/ROW5: D7.2 (A), SW41.1, SW42.1, SW43.1, SW44.1, SW45.1, SW46.1, SW47.1, SW48.1
/Keyboard/ROW6: D8.2 (A), SW49.1, SW50.1, SW51.1, SW52.1, SW53.1, SW54.1, SW55.1, SW56.1
/Keyboard/ROW7: D9.2 (A), SW57.1, SW58.1, SW59.1, SW60.1, SW61.1, SW62.1, SW63.1, SW64.1
/Keyboard/RUS_LAT: RN4.2 (R1), SW67.1, U5.10 (PC7)
/Keyboard/RUS_LAT_LED: U5.17 (PC3), U19.1
/Keyboard/TAPE_IN: D1.1 (K), R4.1, U5.13 (PC4)
/Keyboard/TAPE_OUT: R7.2, U5.14 (PC0)
/Keyboard/~RUS_LAT_LED: D11.1 (K), U19.2
/~PPI1_CS: U5.6 (~CS); also elsewhere on the board
A0: U5.9 (A0); also elsewhere on the board
A1: U5.8 (A1); also elsewhere on the board
D0: U5.34 (D0); also elsewhere on the board
D1: U5.33 (D1); also elsewhere on the board
D2: U5.32 (D2); also elsewhere on the board
D3: U5.31 (D3); also elsewhere on the board
D4: U5.30 (D4); also elsewhere on the board
D5: U5.29 (D5); also elsewhere on the board
D6: U5.28 (D6); also elsewhere on the board
D7: U5.27 (D7); also elsewhere on the board
GND: C31.1, C42.2, D1.2 (A), D10.1 (K), J4.0, J4.1, J4.2, J4.3, J4.8, R8.2, R14.2, R15.2, SW65.2, SW66.2, SW67.2, U5.7 (GND), U21.3 (+); also elsewhere on the board
unnamed: C31.2, C32.2, R7.1, R8.1
unnamed: C32.1, J4.4
unnamed: C39.1, J4.5, R15.1
unnamed: C39.2, C42.1, R14.1, U21.2 (-)
unnamed: R4.2, U21.6
PIT2_ENA: U5.16 (PC2); also elsewhere on the board
PIT_PLUP: RN2.2 (R1); also elsewhere on the board
RESET: U5.35 (RESET); also elsewhere on the board
SER_PLUP: RN2.3 (R2); also elsewhere on the board
SPKR_ENA: U5.15 (PC1); also elsewhere on the board
VCC: R12.1, R13.1, RN2.1 (common), RN3.1 (common), RN4.1 (common), U5.26 (VCC), U21.7 (V+); also elsewhere on the board
~RD: U5.5 (~RD); also elsewhere on the board
~WR: U5.36 (~WR); also elsewhere on the board

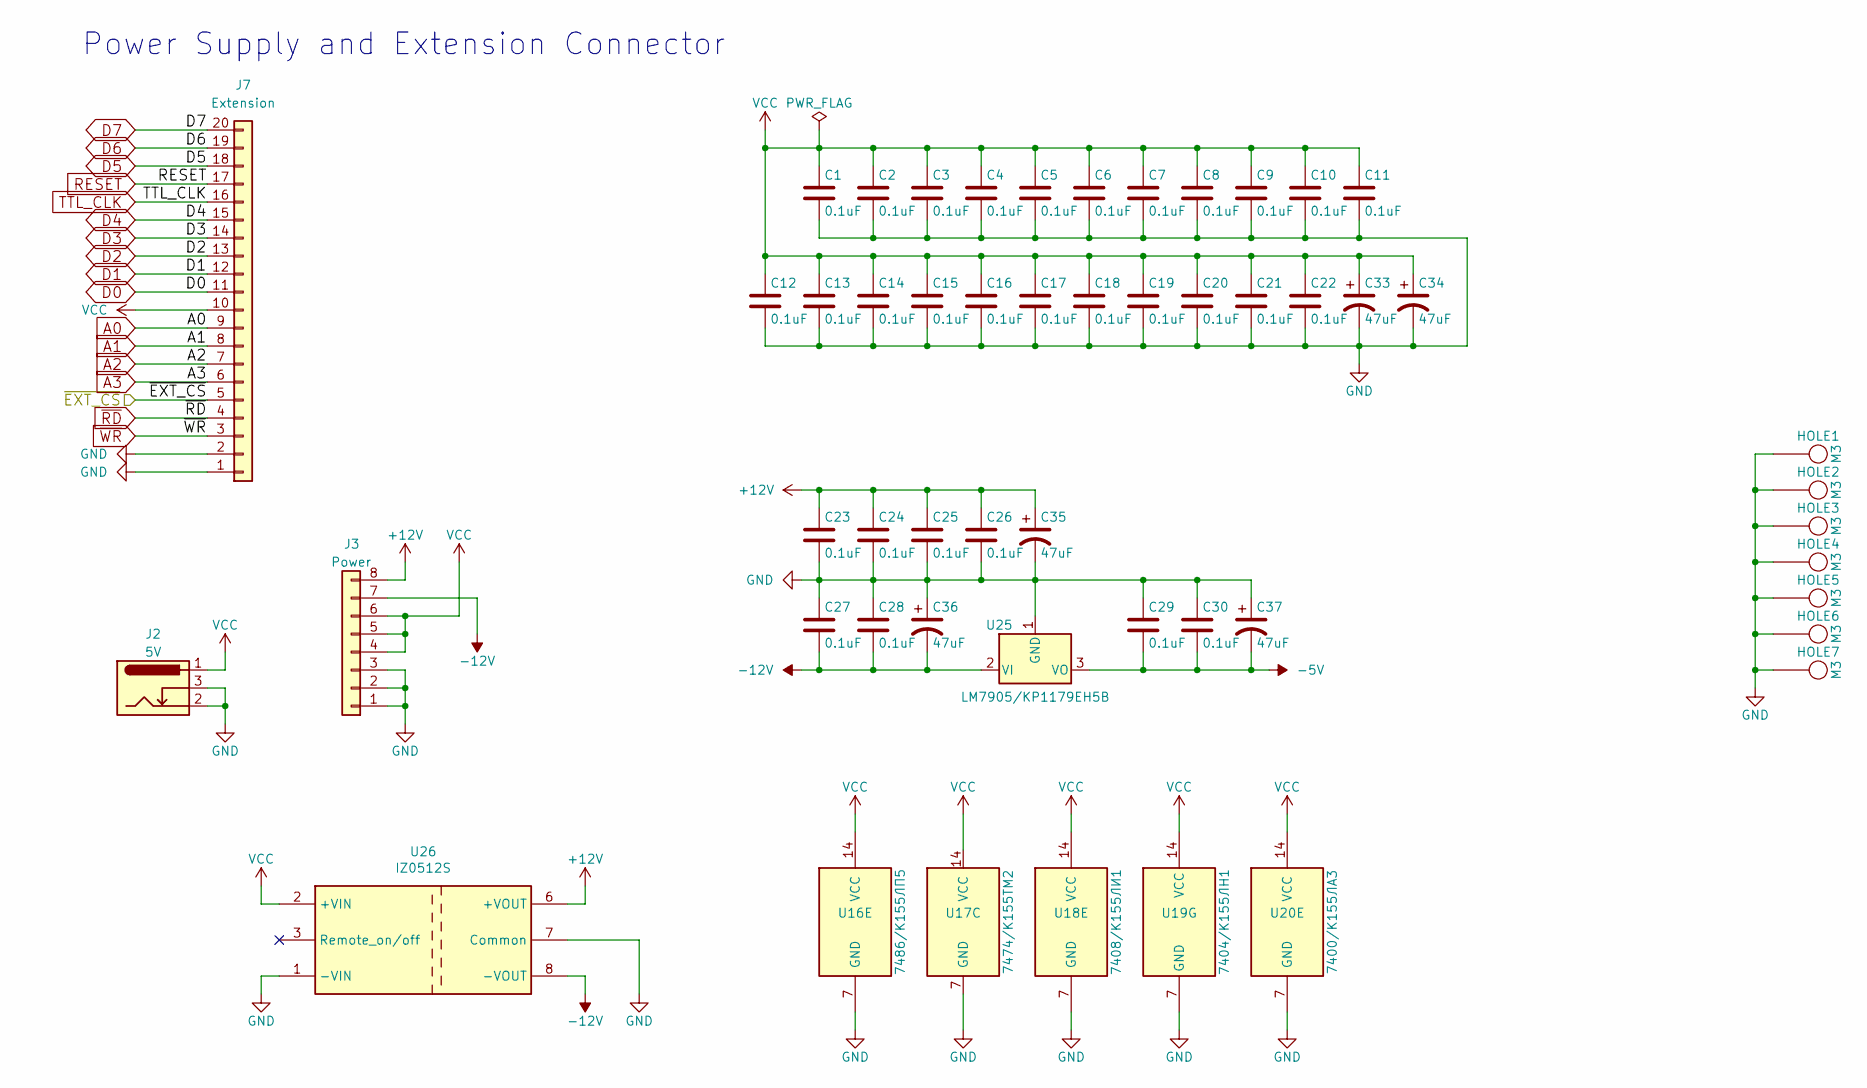
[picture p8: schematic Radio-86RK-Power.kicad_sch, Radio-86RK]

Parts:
C1, C2, C3, C4, C5, C6, C7, C8, C9, C10, C11, C12, C13, C14, C15, C16, C17, C18, C19, C20, C21, C22, C23, C24, C25, C26, C27, C28, C29, C30: 0.1uF; Cap_Cer_508
C33, C34, C35, C36, C37: 47uF; Cap_Elec_Radial_6.3mm
HOLE1, HOLE2, HOLE3, HOLE4, HOLE5, HOLE6, HOLE7: M3; Hole_3mm
J2: 5V; Conn_Power_Jack_Circular_Pads
J3: Power; Conn_Friction_Lock_8P_2.54mm
J7: Extension; Conn_Pin_Header_20x1_2.54mm
U16: 7486/К155ЛП5; IC_DIP14_300
U17: 7474/К155ТМ2; IC_DIP14_300
U18: 7408/К155ЛИ1; IC_DIP14_300
U19: 7404/К155ЛН1; IC_DIP14_300
U20: 7400/К155ЛА3; IC_DIP14_300
U25: LM7905/КР1179ЕН5В; IC_TO220-3_Vert
U26: IZ0512S; DC-DC_SIP8

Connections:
+12V: C23.1, C24.1, C25.1, C26.1, C35.1, J3.8, U26.6 (+VOUT); also elsewhere on the board
-5V: C29.2, C30.2, C37.2, U25.3 (VO); also elsewhere on the board
-12V: C27.2, C28.2, C36.2, J3.7, U25.2 (VI), U26.8 (-VOUT); also elsewhere on the board
/~EXT_CS: J7.5; also elsewhere on the board
A0: J7.9; also elsewhere on the board
A1: J7.8; also elsewhere on the board
A2: J7.7; also elsewhere on the board
A3: J7.6; also elsewhere on the board
D0: J7.11; also elsewhere on the board
D1: J7.12; also elsewhere on the board
D2: J7.13; also elsewhere on the board
D3: J7.14; also elsewhere on the board
D4: J7.15; also elsewhere on the board
D5: J7.18; also elsewhere on the board
D6: J7.19; also elsewhere on the board
D7: J7.20; also elsewhere on the board
GND: C1.2, C2.2, C3.2, C4.2, C5.2, C6.2, C7.2, C8.2, C9.2, C10.2, C11.2, C12.2, C13.2, C14.2, C15.2, C16.2, C17.2, C18.2, C19.2, C20.2, C21.2, C22.2, C23.2, C24.2, C25.2, C26.2, C27.1, C28.1, C29.1, C30.1, C33.2, C34.2, C35.2, C36.1, C37.1, HOLE1.1, HOLE2.1, HOLE3.1, HOLE4.1, HOLE5.1, HOLE6.1, HOLE7.1, J2.2, J2.3, J3.1, J3.2, J3.3, J7.1, J7.2, U16.7 (GND), U17.7 (GND), U18.7 (GND), U19.7 (GND), U20.7 (GND), U25.1 (GND), U26.1 (-VIN), U26.7 (Common); also elsewhere on the board
RESET: J7.17; also elsewhere on the board
TTL_CLK: J7.16; also elsewhere on the board
VCC: C1.1, C2.1, C3.1, C4.1, C5.1, C6.1, C7.1, C8.1, C9.1, C10.1, C11.1, C12.1, C13.1, C14.1, C15.1, C16.1, C17.1, C18.1, C19.1, C20.1, C21.1, C22.1, C33.1, C34.1, J2.1, J3.4, J3.5, J3.6, J7.10, U16.14 (VCC), U17.14 (VCC), U18.14 (VCC), U19.14 (VCC), U20.14 (VCC), U26.2 (+VIN); also elsewhere on the board
~RD: J7.4; also elsewhere on the board
~WR: J7.3; also elsewhere on the board

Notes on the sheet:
Power Supply and Extension Connector

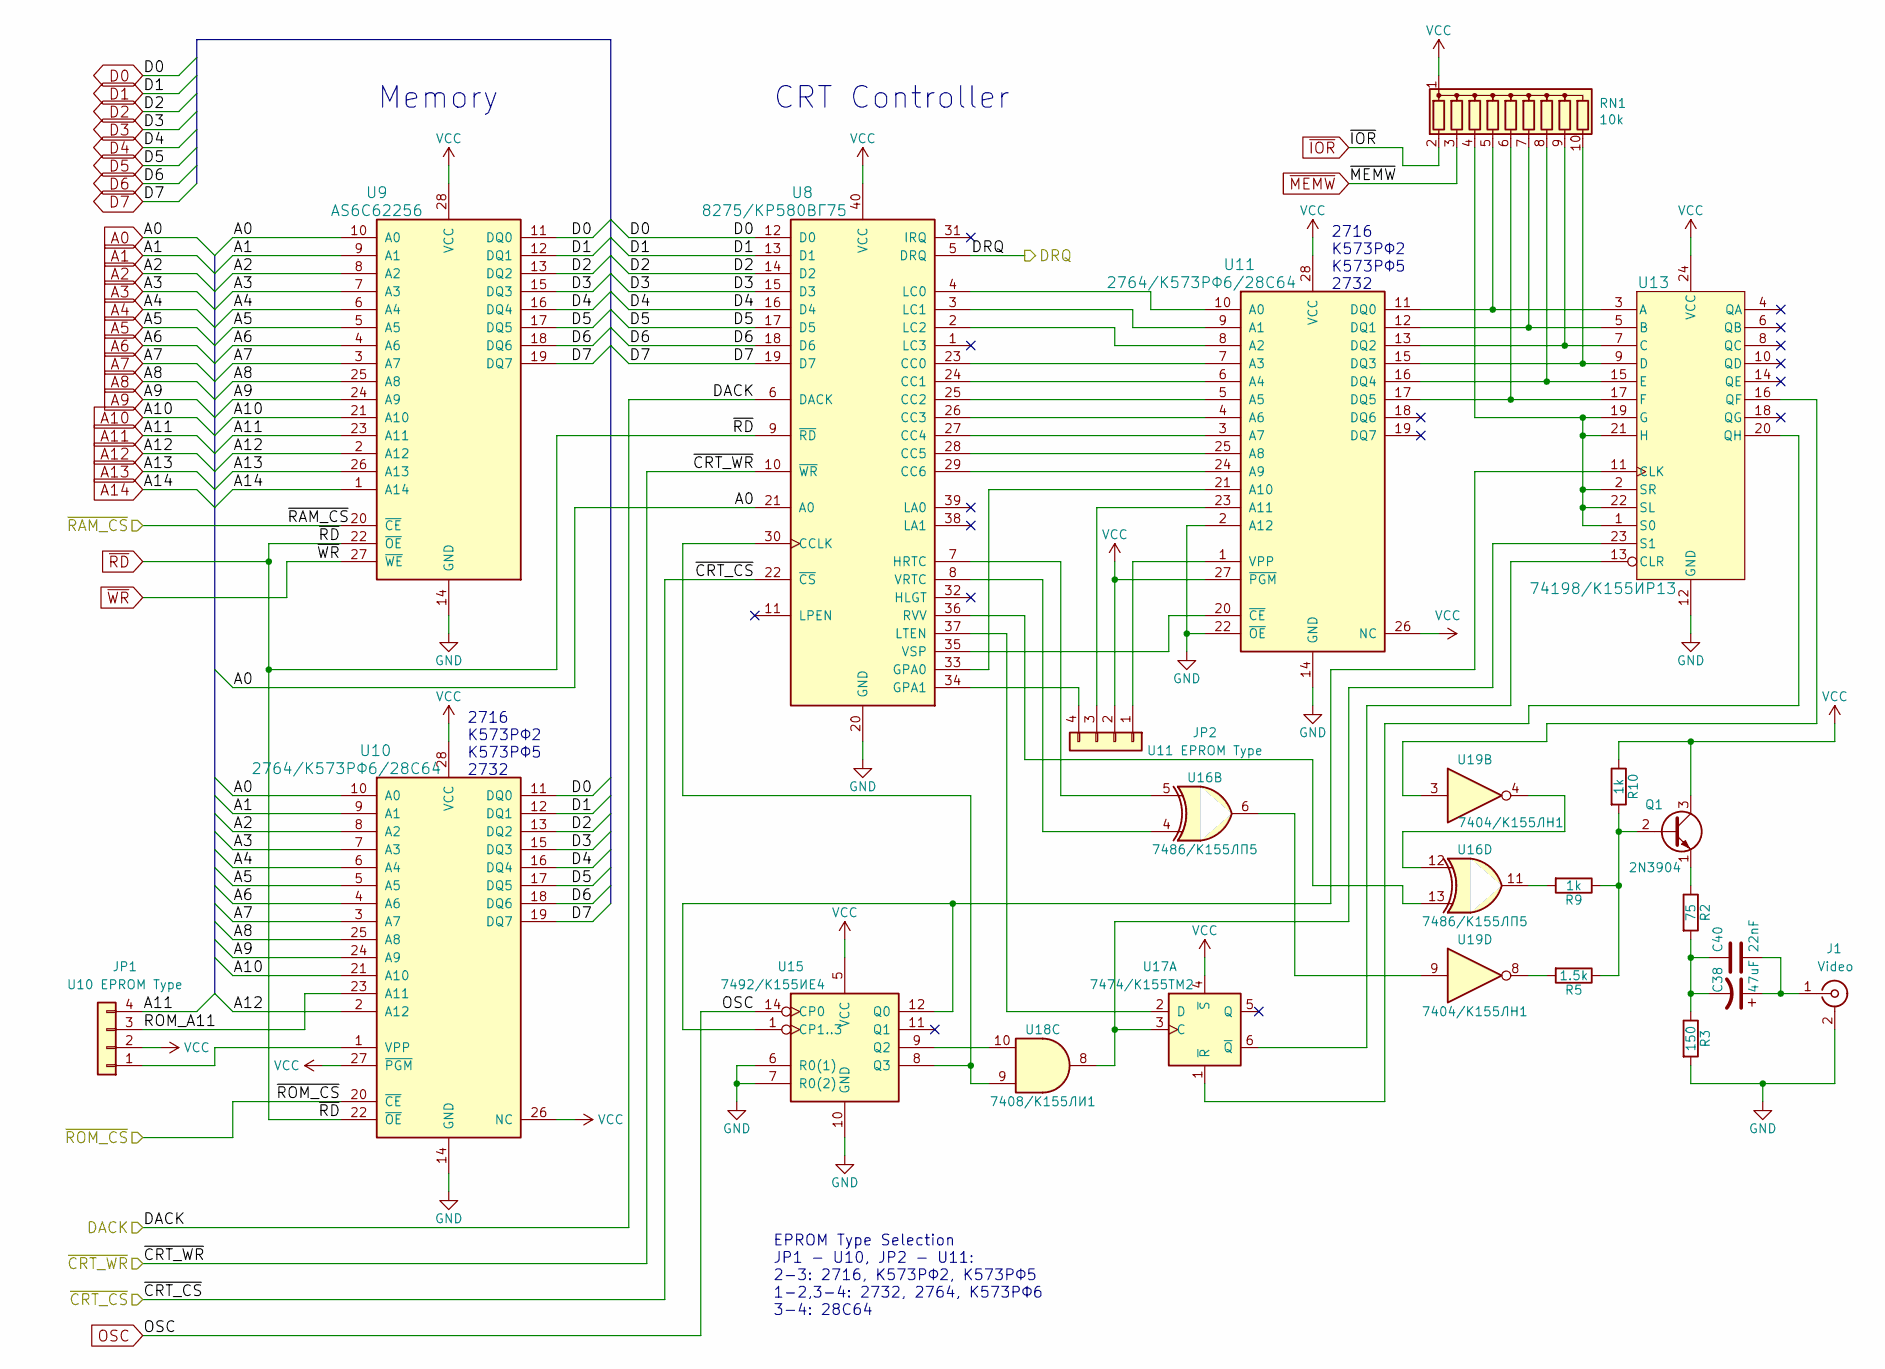
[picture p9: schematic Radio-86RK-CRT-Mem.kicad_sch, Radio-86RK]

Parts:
C38: 47uF; Cap_Elec_Radial_6.3mm
C40: 22nF; Cap_Cer_508
J1: Video; Conn_RCA_Right
JP1: U10 EPROM Type; Conn_Pin_Header_4x1_2.54mm
JP2: U11 EPROM Type; Conn_Pin_Header_4x1_2.54mm
Q1: 2N3904; Transistor_TO92_EBC_254
R2: 75; Res_762
R3: 150; Res_762
R5: 1.5k; Res_762
R9, R10: 1k; Res_762
RN1: 10k; Conn_SIL10
U8: 8275/КР580ВГ75; IC_DIP40_600
U9: AS6C62256; IC_DIP28_600
U10, U11: 2764/К573РФ6/28C64; IC_DIP28_600
U13: 74198/К155ИР13; IC_DIP24_600
U15: 7492/К155ИЕ4; IC_DIP14_300
U16: 7486/К155ЛП5; IC_DIP14_300
U17: 7474/К155ТМ2; IC_DIP14_300
U18: 7408/К155ЛИ1; IC_DIP14_300
U19: 7404/К155ЛН1; IC_DIP14_300

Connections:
/CRT_Memory/ROM_A11: JP1.3, U10.23 (A11)
/DACK: U8.6 (DACK); also elsewhere on the board
/DRQ: U8.5 (DRQ); also elsewhere on the board
/~CRT_CS: U8.22 (~CS); also elsewhere on the board
/~CRT_WR: U8.10 (~WR); also elsewhere on the board
/~RAM_CS: U9.20 (~CE); also elsewhere on the board
/~ROM_CS: U10.20 (~CE); also elsewhere on the board
A0: U8.21 (A0), U9.10 (A0), U10.10 (A0); also elsewhere on the board
A1: U9.9 (A1), U10.9 (A1); also elsewhere on the board
A2: U9.8 (A2), U10.8 (A2); also elsewhere on the board
A3: U9.7 (A3), U10.7 (A3); also elsewhere on the board
A4: U9.6 (A4), U10.6 (A4); also elsewhere on the board
A5: U9.5 (A5), U10.5 (A5); also elsewhere on the board
A6: U9.4 (A6), U10.4 (A6); also elsewhere on the board
A7: U9.3 (A7), U10.3 (A7); also elsewhere on the board
A8: U9.25 (A8), U10.25 (A8); also elsewhere on the board
A9: U9.24 (A9), U10.24 (A9); also elsewhere on the board
A10: U9.21 (A10), U10.21 (A10); also elsewhere on the board
A11: JP1.4, U9.23 (A11); also elsewhere on the board
A12: U9.2 (A12), U10.2 (A12); also elsewhere on the board
A13: U9.26 (A13); also elsewhere on the board
A14: U9.1 (A14); also elsewhere on the board
D0: U8.12 (D0), U9.11 (DQ0), U10.11 (DQ0); also elsewhere on the board
D1: U8.13 (D1), U9.12 (DQ1), U10.12 (DQ1); also elsewhere on the board
D2: U8.14 (D2), U9.13 (DQ2), U10.13 (DQ2); also elsewhere on the board
D3: U8.15 (D3), U9.15 (DQ3), U10.15 (DQ3); also elsewhere on the board
D4: U8.16 (D4), U9.16 (DQ4), U10.16 (DQ4); also elsewhere on the board
D5: U8.17 (D5), U9.17 (DQ5), U10.17 (DQ5); also elsewhere on the board
D6: U8.18 (D6), U9.18 (DQ6), U10.18 (DQ6); also elsewhere on the board
D7: U8.19 (D7), U9.19 (DQ7), U10.19 (DQ7); also elsewhere on the board
GND: J1.2 (Ext), R3.2, U8.20 (GND), U9.14 (GND), U10.14 (GND), U11.2 (A12), U11.14 (GND), U11.22 (~OE), U13.12 (GND), U15.6 (R0(1)), U15.7 (R0(2)), U15.10 (GND); also elsewhere on the board
unnamed: C38.1, C40.2, J1.1 (In)
unnamed: C38.2, C40.1, R2.2, R3.1
unnamed: JP1.1, U10.1 (VPP)
unnamed: JP2.3, U11.23 (A11)
unnamed: Q1.1 (E), R2.1
unnamed: Q1.2 (B), R5.1, R9.1, R10.2
unnamed: R5.2, U19.8
unnamed: R9.2, U16.11
unnamed: RN1.4 (R3), U13.1 (S0), U13.2 (SR), U13.19 (G), U13.21 (H), U13.22 (SL)
unnamed: RN1.5 (R4), U11.11 (DQ0), U13.3 (A)
unnamed: RN1.6 (R5), U11.17 (DQ5), U13.17 (F)
unnamed: RN1.7 (R6), U11.12 (DQ1), U13.5 (B)
unnamed: RN1.8 (R7), U11.16 (DQ4), U13.15 (E)
unnamed: RN1.9 (R8), U11.13 (DQ2), U13.7 (C)
unnamed: RN1.10 (R9), U11.15 (DQ3), U13.9 (D)
unnamed: U8.2 (LC2), U11.8 (A2)
unnamed: U8.3 (LC1), U11.9 (A1)
unnamed: U8.4 (LC0), U11.10 (A0)
unnamed: U8.23 (CC0), U11.7 (A3)
unnamed: U8.24 (CC1), U11.6 (A4)
unnamed: U8.25 (CC2), U11.5 (A5)
unnamed: U8.26 (CC3), U11.4 (A6)
unnamed: U8.27 (CC4), U11.3 (A7)
unnamed: U8.28 (CC5), U11.25 (A8)
unnamed: U8.29 (CC6), U11.24 (A9)
unnamed: U8.33 (GPA0), U11.21 (A10)
unnamed: JP2.4, U8.34 (GPA1)
unnamed: U8.35 (VSP), U11.20 (~CE)
unnamed: JP2.1, U11.1 (VPP)
unnamed: U13.11 (CLK), U15.1 (CP1..3), U15.12 (Q0)
unnamed: U13.13 (CLR), U17.6 (~Q)
unnamed: U13.16 (QF), U19.3
unnamed: U13.20 (QH), U17.1 (~R)
unnamed: U13.23 (S1), U17.3 (C), U18.8
unnamed: U8.30 (CCLK), U15.8 (Q3), U18.9
unnamed: U15.9 (Q2), U18.10
unnamed: U8.8 (VRTC), U16.4
unnamed: U8.7 (HRTC), U16.5
unnamed: U16.6, U19.9
unnamed: U16.12, U19.4
unnamed: U8.36 (RVV), U16.13
unnamed: U8.37 (LTEN), U17.2 (D)
OSC: U15.14 (CP0); also elsewhere on the board
VCC: JP1.2, JP2.2, Q1.3 (C), R10.1, RN1.1 (common), U8.40 (VCC), U9.28 (VCC), U10.26 (NC), U10.27 (~PGM), U10.28 (VCC), U11.26 (NC), U11.27 (~PGM), U11.28 (VCC), U13.24 (VCC), U15.5 (VCC), U17.4 (~S); also elsewhere on the board
~IOR: RN1.2 (R1); also elsewhere on the board
~MEMW: RN1.3 (R2); also elsewhere on the board
~RD: U8.9 (~RD), U9.22 (~OE), U10.22 (~OE); also elsewhere on the board
~WR: U9.27 (~WE); also elsewhere on the board

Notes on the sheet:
EPROM Type Selection JP1 - U10, JP2 - U11: 2-3: 2716, К573РФ2, К573РФ5 1-2,3-4: 2732, 2764, К573РФ6 3-4: 28C64
2716 К573РФ2 К573РФ5 2732
Memory
CRT Controller

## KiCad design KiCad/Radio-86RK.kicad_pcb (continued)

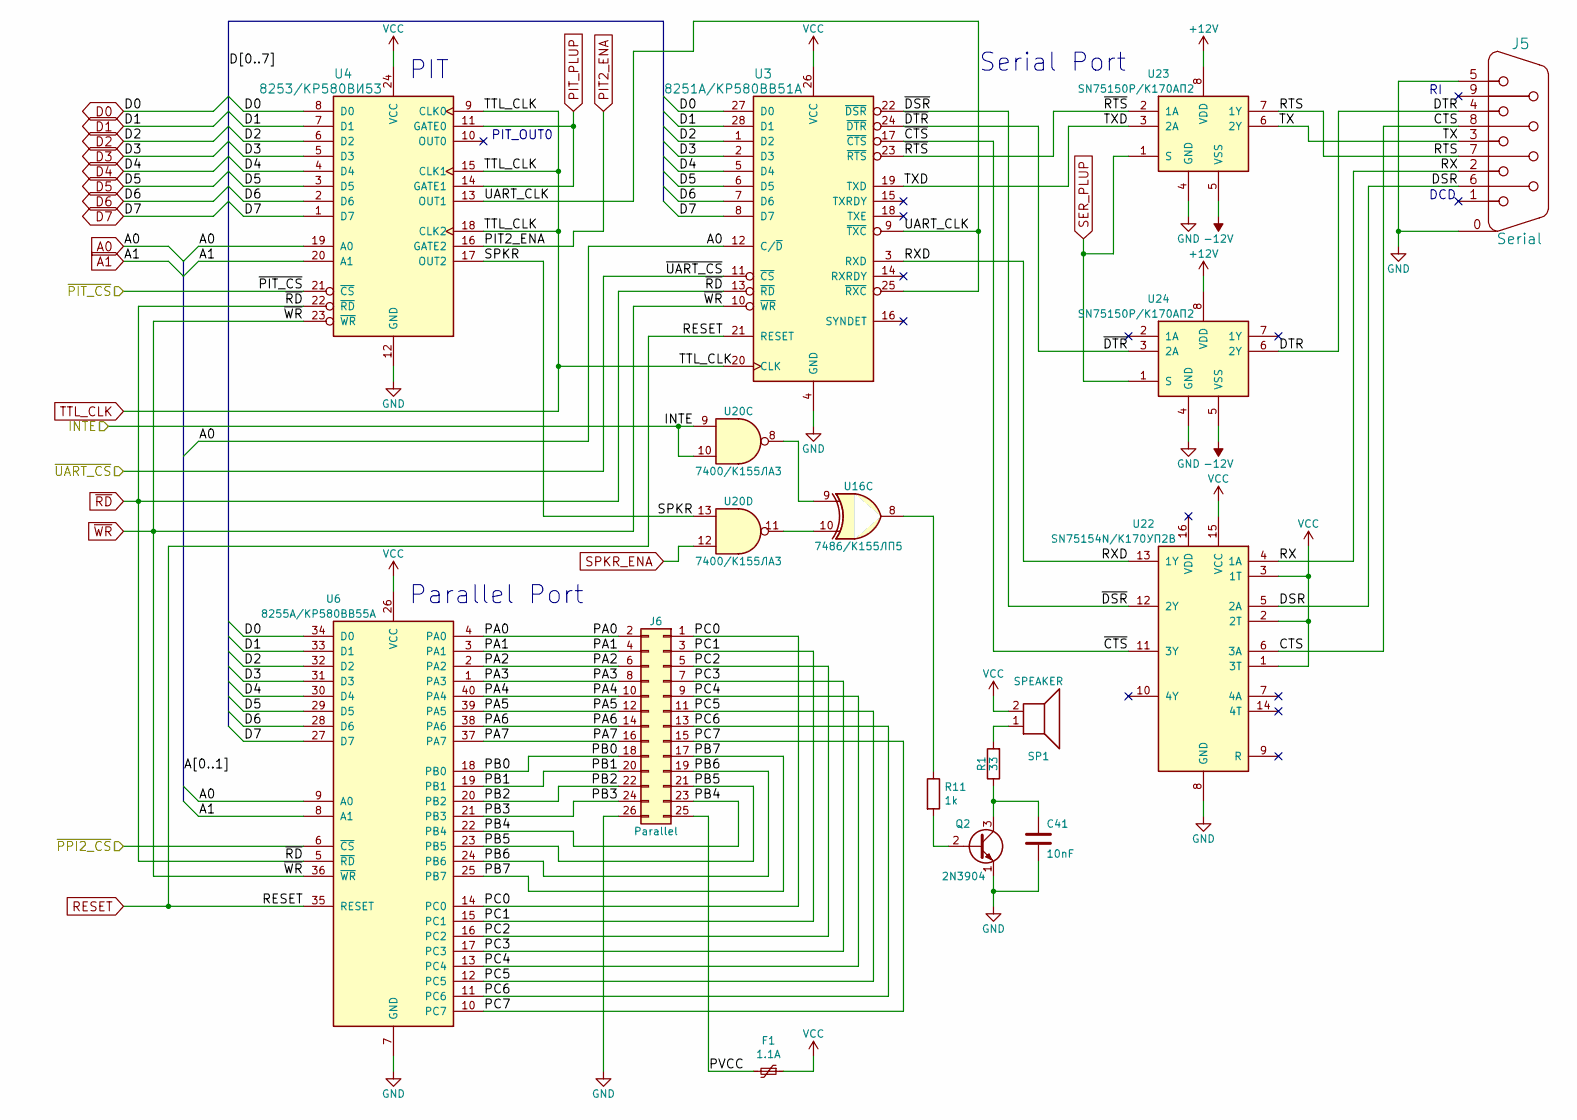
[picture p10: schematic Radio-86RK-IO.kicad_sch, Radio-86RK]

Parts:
C41: 10nF; Cap_Cer_508
F1: 1.1A; Cap_Cer_508
J5: Serial; Conn_Dsub_DE9M
J6: Parallel; Conn_Pin_Header_13x2_2.54mm_Shrouded
Q2: 2N3904; Transistor_TO92_EBC_254
R1: 33; Res_762
R11: 1k; Res_762
SP1: SPEAKER; Speaker_12mm
U3: 8251A/КР580ВВ51А; IC_DIP28_600
U4: 8253/КР580ВИ53; IC_DIP24_600
U6: 8255A/КР580ВВ55А; IC_DIP40_600
U16: 7486/К155ЛП5; IC_DIP14_300
U20: 7400/К155ЛА3; IC_DIP14_300
U22: SN75154N/К170УП2В; IC_DIP16_300
U23, U24: SN75150P/К170АП2; IC_DIP8_300

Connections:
+12V: U23.8 (VDD), U24.8 (VDD); also elsewhere on the board
-12V: U23.5 (VSS), U24.5 (VSS); also elsewhere on the board
/INTE: U20.9, U20.10; also elsewhere on the board
/Input_Output/CTS: J5.8, U22.6 (3A)
/Input_Output/DSR: J5.6, U22.5 (2A)
/Input_Output/DTR: J5.4, U24.6 (2Y)
/Input_Output/PA0: J6.2, U6.4 (PA0)
/Input_Output/PA1: J6.4, U6.3 (PA1)
/Input_Output/PA2: J6.6, U6.2 (PA2)
/Input_Output/PA3: J6.8, U6.1 (PA3)
/Input_Output/PA4: J6.10, U6.40 (PA4)
/Input_Output/PA5: J6.12, U6.39 (PA5)
/Input_Output/PA6: J6.14, U6.38 (PA6)
/Input_Output/PA7: J6.16, U6.37 (PA7)
/Input_Output/PB0: J6.18, U6.18 (PB0)
/Input_Output/PB1: J6.20, U6.19 (PB1)
/Input_Output/PB2: J6.22, U6.20 (PB2)
/Input_Output/PB3: J6.24, U6.21 (PB3)
/Input_Output/PB4: J6.23, U6.22 (PB4)
/Input_Output/PB5: J6.21, U6.23 (PB5)
/Input_Output/PB6: J6.19, U6.24 (PB6)
/Input_Output/PB7: J6.17, U6.25 (PB7)
/Input_Output/PC0: J6.1, U6.14 (PC0)
/Input_Output/PC1: J6.3, U6.15 (PC1)
/Input_Output/PC2: J6.5, U6.16 (PC2)
/Input_Output/PC3: J6.7, U6.17 (PC3)
/Input_Output/PC4: J6.9, U6.13 (PC4)
/Input_Output/PC5: J6.11, U6.12 (PC5)
/Input_Output/PC6: J6.13, U6.11 (PC6)
/Input_Output/PC7: J6.15, U6.10 (PC7)
/Input_Output/PVCC: F1.2, J6.25
/Input_Output/RTS: J5.7, U23.7 (1Y)
/Input_Output/RX: J5.2, U22.4 (1A)
/Input_Output/RXD: U3.3 (RXD), U22.13 (1Y)
/Input_Output/SPKR: U4.17 (OUT2), U20.13
/Input_Output/TX: J5.3, U23.6 (2Y)
/Input_Output/TXD: U3.19 (TXD), U23.3 (2A)
/Input_Output/UART_CLK: U3.9 (~TXC), U3.25 (~RXC), U4.13 (OUT1)
/Input_Output/~CTS: U3.17 (~CTS), U22.11 (3Y)
/Input_Output/~DSR: U3.22 (~DSR), U22.12 (2Y)
/Input_Output/~DTR: U3.24 (~DTR), U24.3 (2A)
/Input_Output/~RTS: U3.23 (~RTS), U23.2 (1A)
/~PIT_CS: U4.21 (~CS); also elsewhere on the board
/~PPI2_CS: U6.6 (~CS); also elsewhere on the board
/~UART_CS: U3.11 (~CS); also elsewhere on the board
A0: U3.12 (C/~D), U4.19 (A0), U6.9 (A0); also elsewhere on the board
A1: U4.20 (A1), U6.8 (A1); also elsewhere on the board
D0: U3.27 (D0), U4.8 (D0), U6.34 (D0); also elsewhere on the board
D1: U3.28 (D1), U4.7 (D1), U6.33 (D1); also elsewhere on the board
D2: U3.1 (D2), U4.6 (D2), U6.32 (D2); also elsewhere on the board
D3: U3.2 (D3), U4.5 (D3), U6.31 (D3); also elsewhere on the board
D4: U3.5 (D4), U4.4 (D4), U6.30 (D4); also elsewhere on the board
D5: U3.6 (D5), U4.3 (D5), U6.29 (D5); also elsewhere on the board
D6: U3.7 (D6), U4.2 (D6), U6.28 (D6); also elsewhere on the board
D7: U3.8 (D7), U4.1 (D7), U6.27 (D7); also elsewhere on the board
GND: C41.2, J5.0 (GND), J5.5, J6.26, Q2.1 (E), U3.4 (GND), U4.12 (GND), U6.7 (GND), U22.8 (GND), U23.4 (GND), U24.4 (GND); also elsewhere on the board
unnamed: C41.1, Q2.3 (C), R1.1
unnamed: Q2.2 (B), R11.2
unnamed: R1.2, SP1.1
unnamed: R11.1, U16.8
unnamed: U16.9, U20.8
unnamed: U16.10, U20.11
PIT2_ENA: U4.16 (GATE2); also elsewhere on the board
PIT_PLUP: U4.11 (GATE0), U4.14 (GATE1); also elsewhere on the board
RESET: U3.21 (RESET), U6.35 (RESET); also elsewhere on the board
SER_PLUP: U23.1 (S), U24.1 (S); also elsewhere on the board
SPKR_ENA: U20.12; also elsewhere on the board
TTL_CLK: U3.20 (CLK), U4.9 (CLK0), U4.15 (CLK1), U4.18 (CLK2); also elsewhere on the board
VCC: F1.1, SP1.2, U3.26 (VCC), U4.24 (VCC), U6.26 (VCC), U22.1 (3T), U22.2 (2T), U22.3 (1T), U22.15 (VCC); also elsewhere on the board
~RD: U3.13 (~RD), U4.22 (~RD), U6.5 (~RD); also elsewhere on the board
~WR: U3.10 (~WR), U4.23 (~WR), U6.36 (~WR); also elsewhere on the board

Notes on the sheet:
PIT
DCD
PIT_OUT0
Parallel Port
Serial Port

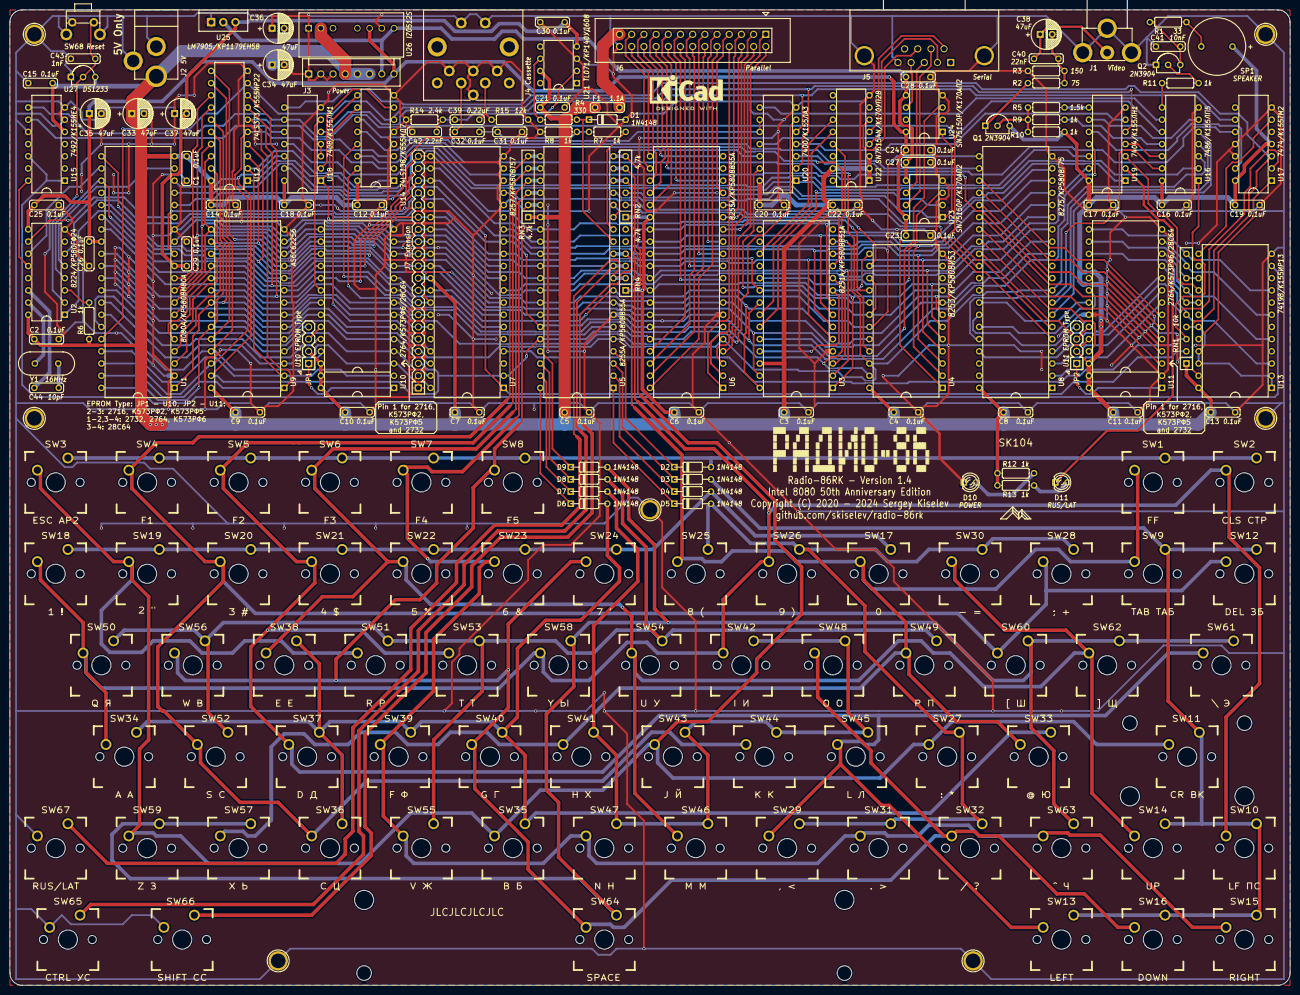
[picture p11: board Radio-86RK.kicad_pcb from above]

Board: 2 copper layers, 266.7 x 203.2 mm, 191 parts (0 on the bottom side), 200 nets.

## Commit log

2026-09-06 Add the KiCad verification harness
    Nothing in this repository could answer the question every board change
    raises: did the manufacturing output move? Five shell scripts had grown up
    around that question, each with its own environment assumptions, none of
    them tested. This replaces them with one stdlib-only package behind a single
    launcher, tools/kicad-verify.py.
    Two gates and one report. The gerber gate exports 22 layers, canonicalises
    them and compares against verify/baseline/strict/. The netlist gate checks
    that every pin still maps to the same net. The rules command reports ERC and
    DRC but is deliberately not a gate: it has no baseline to be right or wrong
    about, and this pre-conversion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
    [Radio-86RK-B_Cu.gbl, Radio-86RK-B_Mask.gbs, Radio-86RK-B_Silkscreen.gbo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]
2026-09-07 Add agent working notes: CLAUDE.md, five skills, and a review log
    This repository had no agent configuration. Every session began by
    rediscovering the same facts: which of eight top-level directories matters
    for what, that two different sets of gerbers exist and mean different
    things, that pcbnew cannot be imported by the system interpreter.
    CLAUDE.md is a map and an opening procedure, not a rulebook. It states only
    what no existing document states -- the repository's layout, that the
    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
2026-09-07 Bring the KiCad 10 board, its libraries and its 3D models onto master
    The board files here have been in KiCad 6 format since v1.4, with the
    modernized project sitting unmerged on a branch. This lands it: KiCad 10
    format, symbols and footprints vendored so a fresh clone opens without a
    sibling checkout, and 3D models on every component.
    The board does not change. That is measured, not asserted: with kicad-cli
    held at the 10.0.4 the baseline records, the KiCad 10 board exports gerbers
    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
    [Radio-86RK-CRT-Mem.kicad_sch, Radio-86RK-IO.kicad_sch, Radio-86RK-Keyboard.kicad_sch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]
2026-09-07 Repair the position CSV kicad-cli emits for a legend containing a quote
    kicad-cli pcb export pos --format csv does not escape a double quote inside
    the Value field. SW19's legend is `2 "`, so it emits
    "SW19","2 "","CHERRY_PCB_100H",28.650000,-117.550000,0.000000,top
    which no CSV reader can parse. Python's csv module does not raise on it
    either: it silently shifts the row's remaining fields, so SW19's Package
    reads as its X coordinate and any consumer filtering on Package drops the
    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
2026-09-07 Bake U26's scale into the model instead of the footprint
    IZ0512S.step is the IA0512S sibling rescaled to the IZ0512S datasheet, and
    that rescale lived in the footprint as (scale 1.1321 1.5107 1.0925) -- the
    only non-unit scale on the board.
    KiCad applies it, so the board has always looked right. KiCadStepUp refuses
    it and forces (1 1 1), because non-uniform scaling of a solid is not a view
    setting, it is corruption of geometry: the part you would cut a case against
    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
    [Radio-86RK.kicad_pcb]

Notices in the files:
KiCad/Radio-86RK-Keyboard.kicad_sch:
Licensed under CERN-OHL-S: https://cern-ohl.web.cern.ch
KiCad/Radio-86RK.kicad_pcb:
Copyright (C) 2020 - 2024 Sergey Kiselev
